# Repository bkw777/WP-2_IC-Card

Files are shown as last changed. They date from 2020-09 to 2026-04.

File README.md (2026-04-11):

# Expansion IC-Card for [TANDY WP-2](tandy.wiki/WP-2), [TANDY WP-3](https://www.retrocoding.uk/tandy-wp-3-word-processor/), [Citizen CBM-10WP](https://web.archive.org/web/20221129054710/http://mo5.com/musee-machines-cbm10wp.html), [NTS WP-10C](https://munk.org/typecast/2020/09/09/tandy-wp-2-user-manual-happy-septandy/)

The TANDY WP-2 and other clones of the Citizen CBM-10WP have an expansion slot that accepts ["IC Cards"](#reference-material).

Here are a few different cards to fit that slot.

* A [battery-backed SRAM card](#sram-card) like the original cards  
* A [non-volatile MRAM card](#mram-card), a RAM card that doesn't need a battery  
* A [ROM card](#rom-card), there is [new software](SOFTWARE) that runs from a rom card but no known images of any old original rom cards  
* A [programming adapter](#programming-adapter) that can read and write both the RAM and ROM cards outside of the WP-2
* A [bus-tap/breakout card](#bus-tap) to allow connecting the bus to a breadboard or logic analyser etc

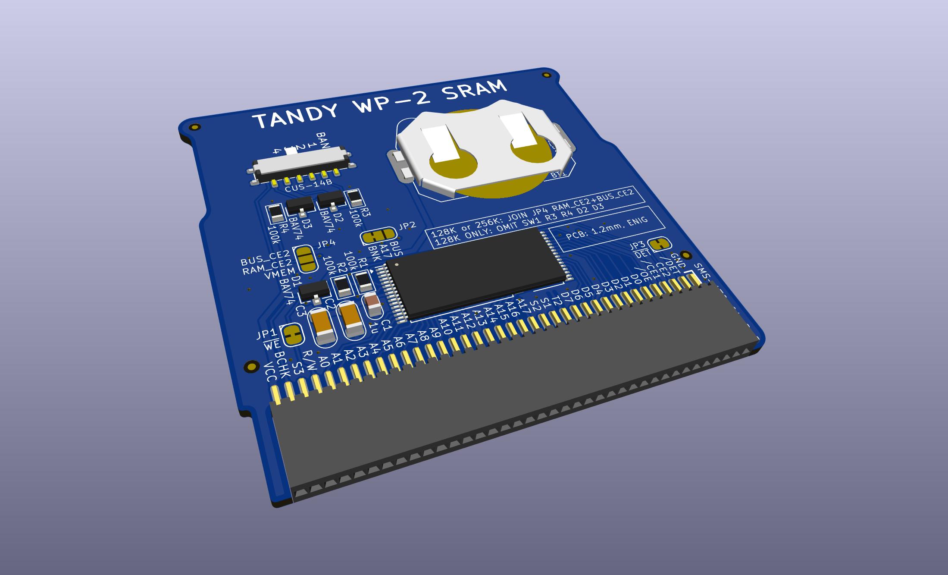
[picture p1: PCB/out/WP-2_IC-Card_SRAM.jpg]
  
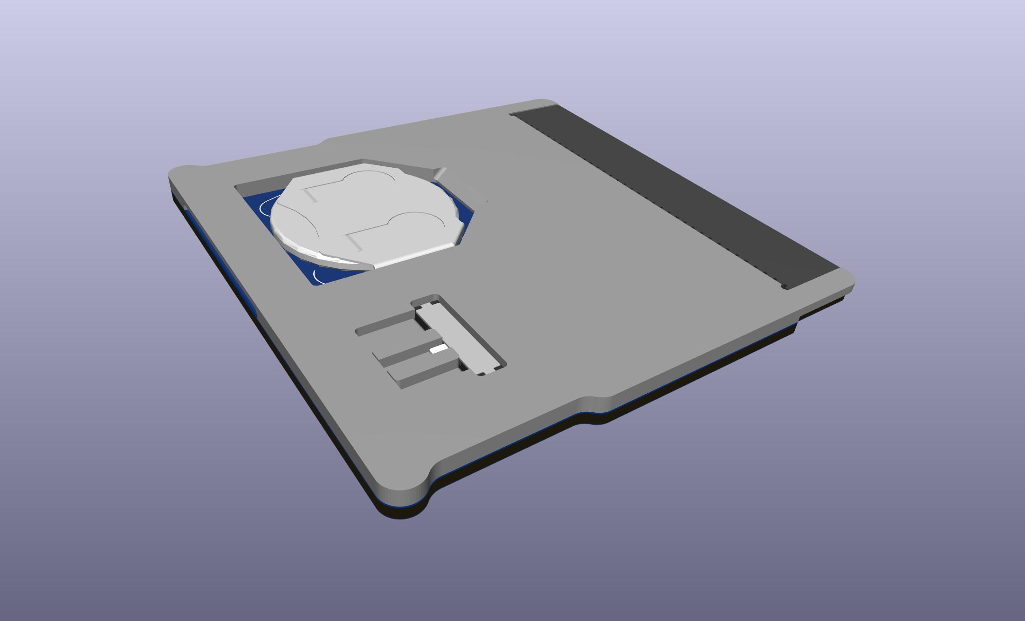
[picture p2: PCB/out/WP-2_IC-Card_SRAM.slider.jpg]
  

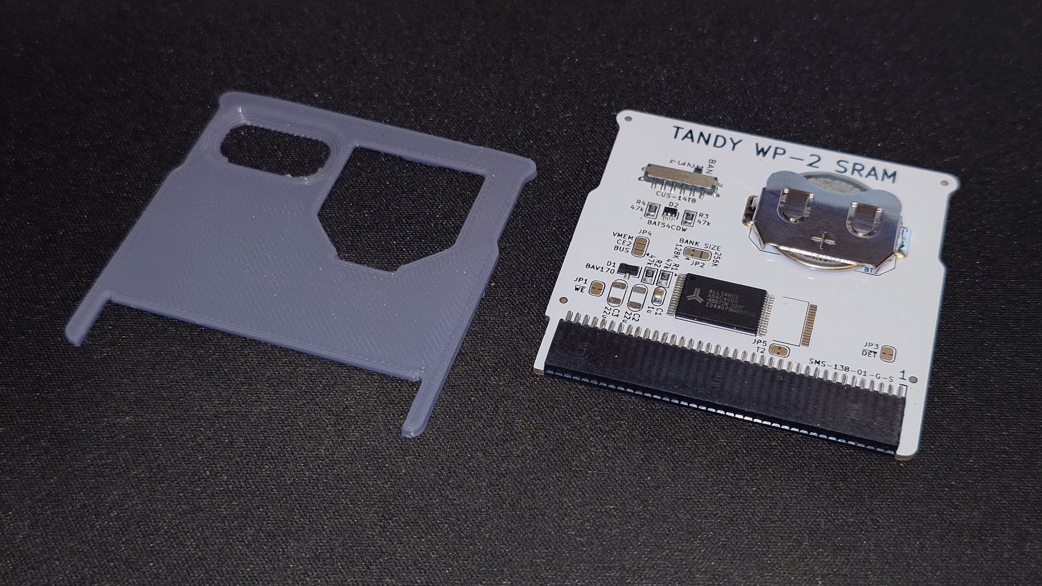
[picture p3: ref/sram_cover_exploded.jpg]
  
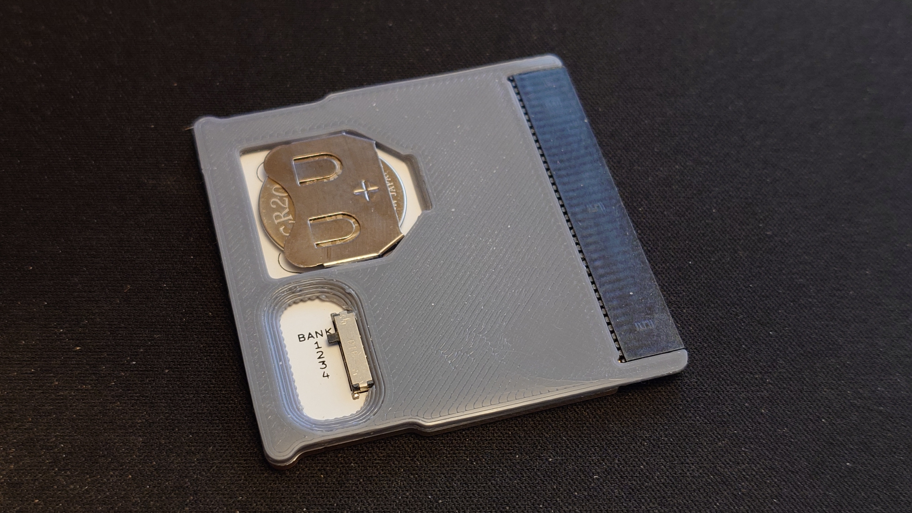
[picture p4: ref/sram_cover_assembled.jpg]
  
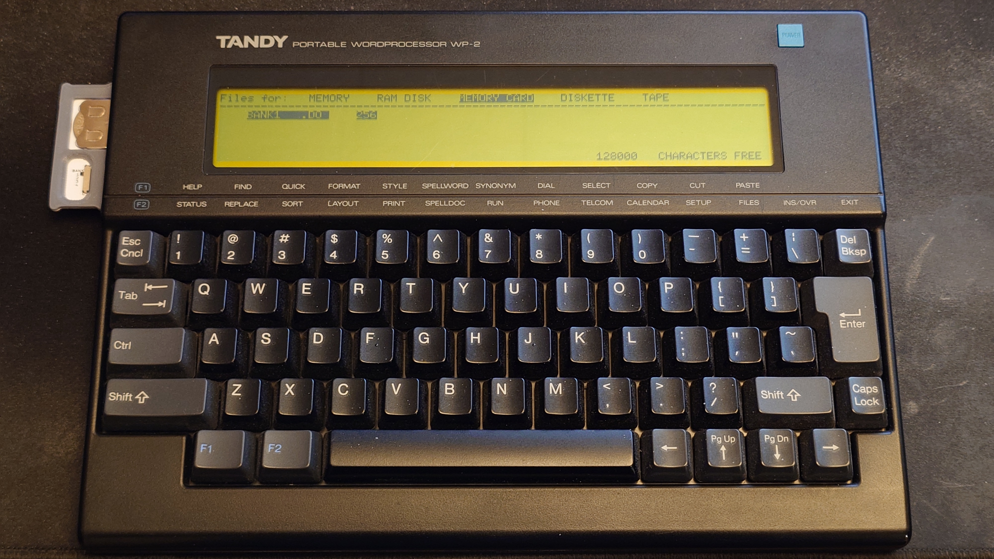
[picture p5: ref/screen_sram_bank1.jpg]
  

## Fabrication & assembly notes

* **REQUIRES 1.2mm PCB**  
The normal default PCB thickness of 1.6mm will NOT fit.  
If you don't remember to manually change the PCB THICKNESS to 1.2mm when ordering, you'll get 1.6mm.  

1.2mm  
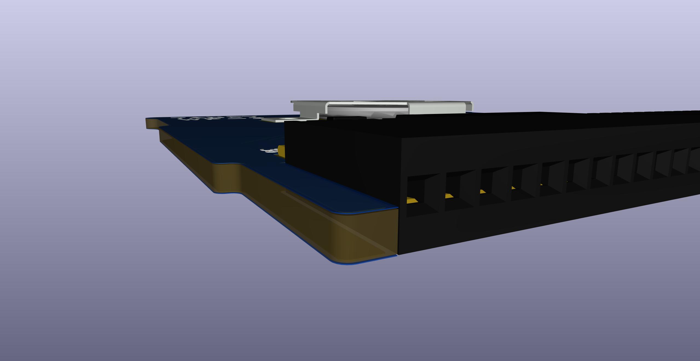
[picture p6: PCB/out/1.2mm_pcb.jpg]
  

1.6mm  
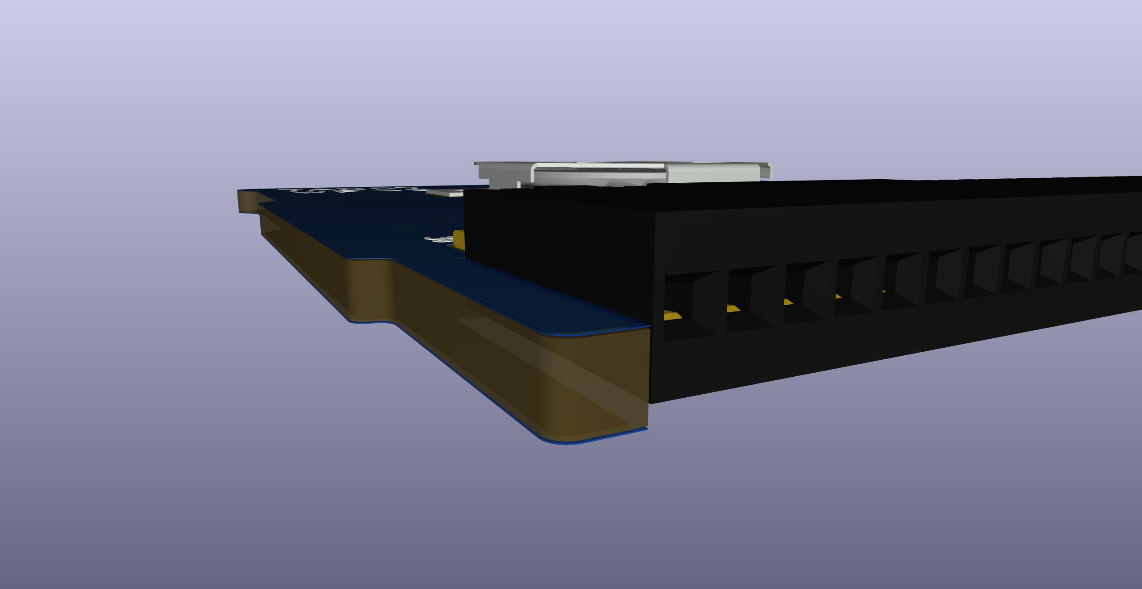
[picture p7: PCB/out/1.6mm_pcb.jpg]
  

* The SRAM card has a battery terminal that should be gold.
ENIG copper finish will give you a better battery terminal without the expense and custom steps of proper selective hard gold.

* Attach the cover with thin 3mm or 1/8" adhesive transfer tape aka "cell phone / tablet screen repair tape".  
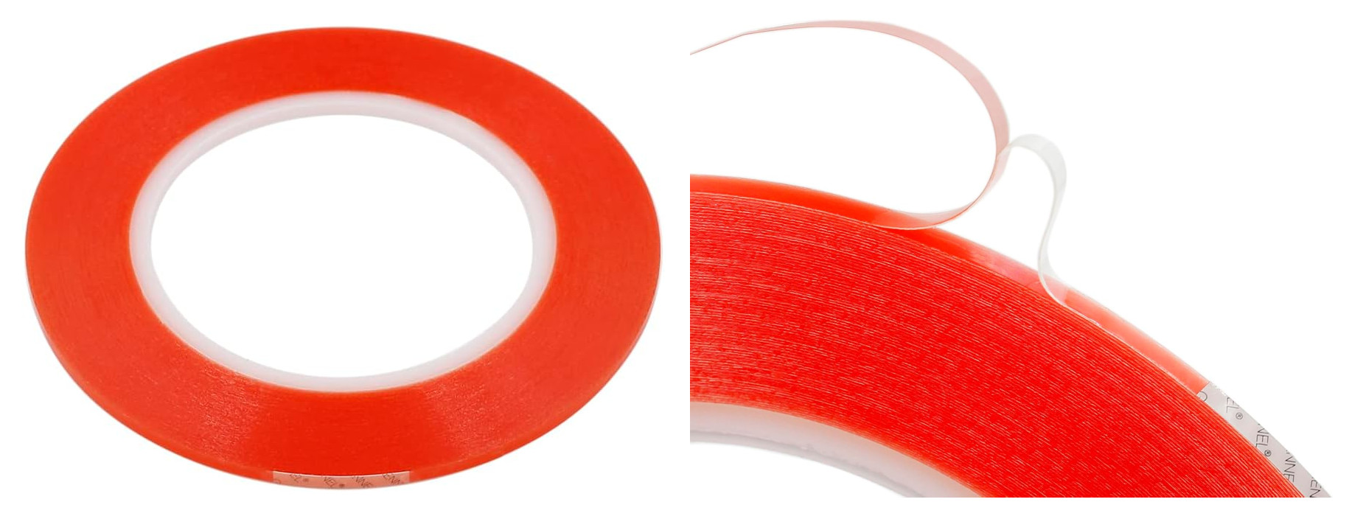
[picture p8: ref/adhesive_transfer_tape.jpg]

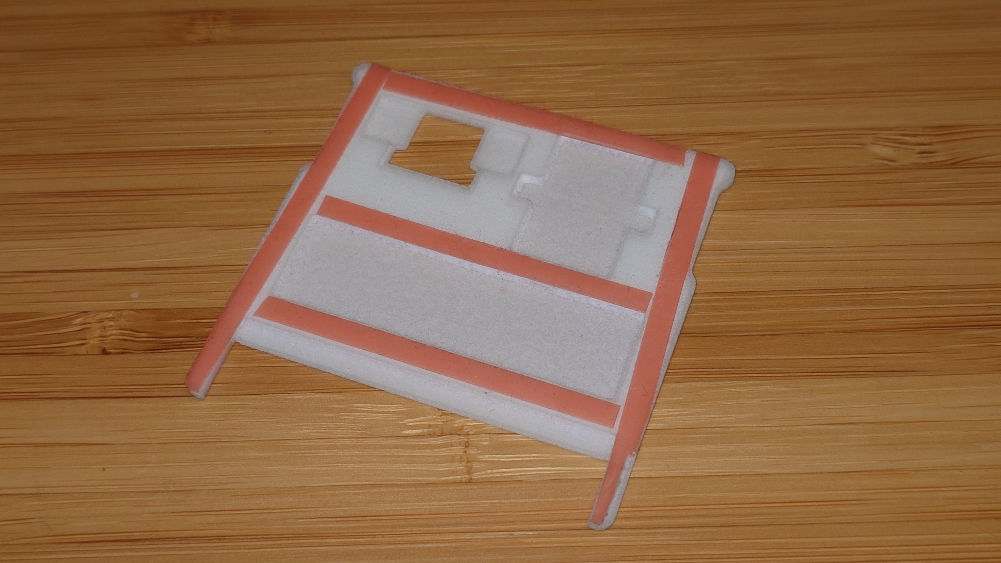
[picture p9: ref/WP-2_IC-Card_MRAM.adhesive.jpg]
 
https://www.amazon.com/dp/B0C78LJLDR/ 0.2mm  
https://www.amazon.com/dp/B0DRV5D4YG/ 0.2mm  
https://www.amazon.com/dp/B078H298G2/ 0.2mm  
https://www.amazon.com/dp/B019OQ4ZG0/ 0.2mm  
https://www.amazon.com/dp/B01N27LYV9/ 0.09mm  

<!-- https://amazon.com/dp/B06Y34587N/ (This one is wider than 5mm but has no carrier film in the middle, just gummy adhesive that squishes into any form, so the width doesn't matter and you can just lay it anywhere right over the chips and pins etc.) -->
Or glue, but adhesive is easier to remove later.  
You can make the cover easy to remove by just using small bits of tape instead of full lengths like the picture. It doesn't take much to hold it on

The cover is not just cosmetic. It prevents the components from catching on the lip of the card slot when inserting & removing, and protects against shorts, and protects against general physical damage to the components.

Similarly, it's a good idea to cover the bottom of the pcb with a piece of 2 inch shipping or packing tape to protect the pcb from scratching and shorting.  
Just lay a simple single piece across the main pcb part along the connector edge but not on the connector.

The various solder-jumpers are mostly for hacking and custom software development like making a ram card emulate a rom card, or possible use in other machines besides the WP-2, for instance maybe some other machine besides the WP-2 could address 256k in ram mode, etc.  
They are pre-connected for normal operation and you normally just ignore them. Don't solder them or cut them.  

The most likely exceptions you might actually use are:  
. On the ROM card, to make a simple 256k rom card with no bank switch or write-enable switch, hard-wired to always be write-enabled via the S3 pin to work with a matching bodge wire mod in the WP-2, solder-blob the S3 pin pads on the (unpopulated) write-enable switch.  
. On the SRAM card, to make a simple 128k ram card with no bank switch, solder-blob RAM_CE2 to BUS_CE2 (or RAM_CE2 to VMEM, it doesn't much matter which, but only one or the other not both!)

Most cards have a few different styles and configurations of the printed cover.  
If you have trouble printing the fancy switch sliders, the "finger" versions are a simpler alternative.  
The switches are optional on all cards, so there are versions without any bank-select or write-enable switches.  
Aside from the pre-generated stl files, you can open the scad file in openscad and use the customizer panel to select different options and generate a new stl file. You don't have to touch the scad code. Just play with a few of the main options at the top of the customizer panel.

Gerbers, BOMs, and STLs are in [releases](../../releases/)

[pictures](https://photos.app.goo.gl/M8KbMLbY8BXGH7LL8)

----

## SRAM CARD  
<!--
[128K SRAM BOM from DigiKey](https://www.digikey.com/short/fdjd3j85)  
[128K SRAM PCB and COVER from PCBWAY](https://www.pcbway.com/project/shareproject/WP_2_RAM_IC_Card.html)  
IMPORTANT, when ordering the PCB:  
* **Thickness: 1.2** <-- MOST IMPORTANT - DO NOT MISS  
* **Min Track/Spacing: 6/6mil**  
The PCBWAY ordering page may auto-select thinner minimum traces which is expensive, but thise pcb actually has all traces at least 0.2mm (7.8mil), so you should manually change the option to 6mil.  
* **Surface Finish: Immersion gold(ENIG)**  
Makes it expensive, but you want the battery terminal to be gold.  
* **Other Special request: Bottom solder mask full cover.**  
There are no openings in the bottom soldermask layer, so you have to tell them that you want 100% soldermask coverage rather than 0% coverage.

You can save some money on the ENIG by using Elecrow instead of PCBWAY.

![](PCB/out/WP-2_IC-Card_SRAM_128K.jpg)  
![](PCB/out/WP-2_IC-Card_SRAM_128K.covered.jpg)  
![](PCB/out/WP-2_IC-Card_SRAM_128K.top.jpg)  
![](PCB/out/WP-2_IC-Card_SRAM_128K.bottom.jpg)  
![](PCB/out/WP-2_IC-Card_SRAM_128K.svg)  
![](COVER/out/WP-2_IC-Card_Cover_SRAM.png)

****
### work in progress updated SRAM card
-->

Fully populated for a 256k or 512k chip  


Configured for a 128k chip  
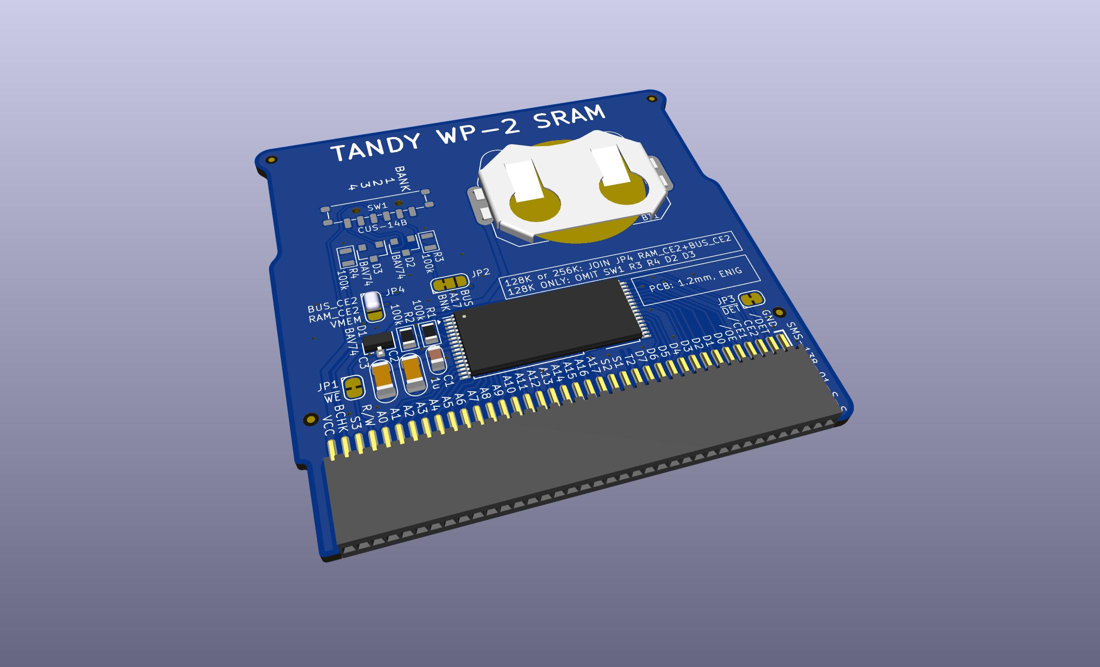
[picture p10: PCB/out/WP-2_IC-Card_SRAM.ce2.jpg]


  
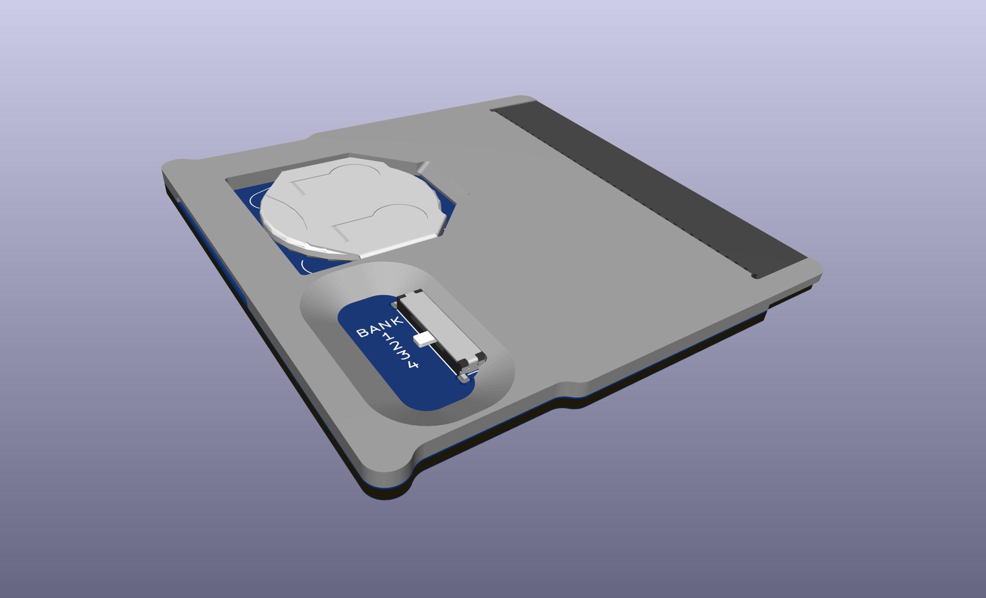
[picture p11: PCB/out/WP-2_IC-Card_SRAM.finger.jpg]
  
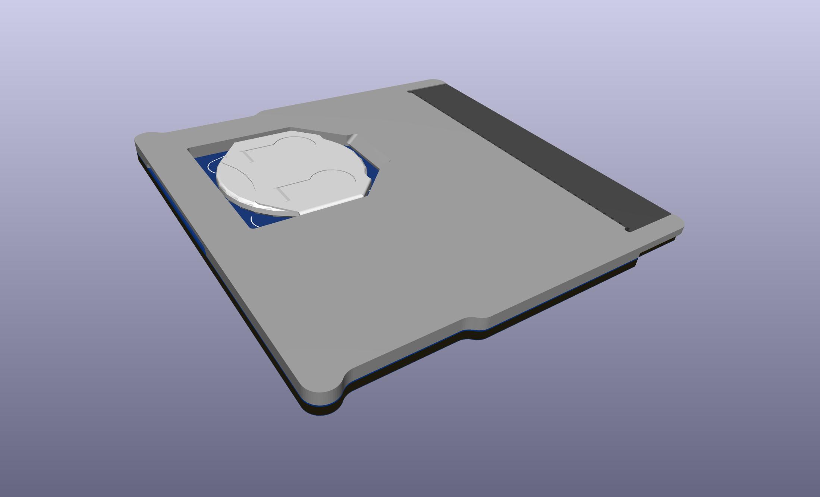
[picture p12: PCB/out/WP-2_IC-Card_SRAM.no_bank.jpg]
  
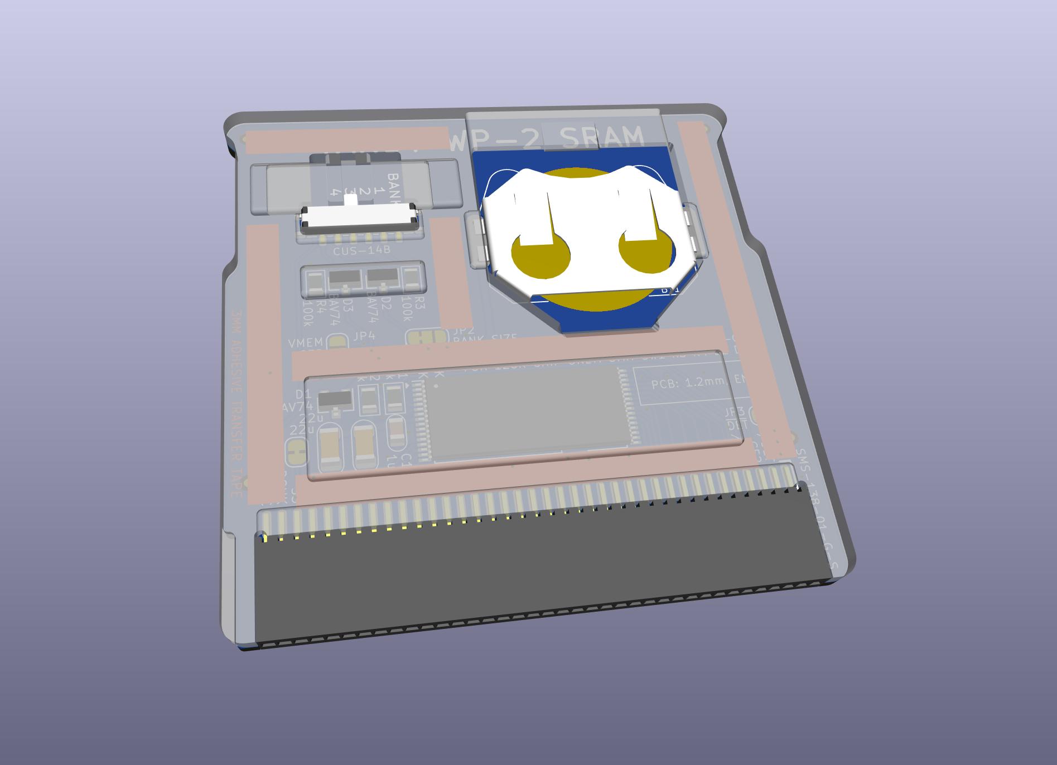
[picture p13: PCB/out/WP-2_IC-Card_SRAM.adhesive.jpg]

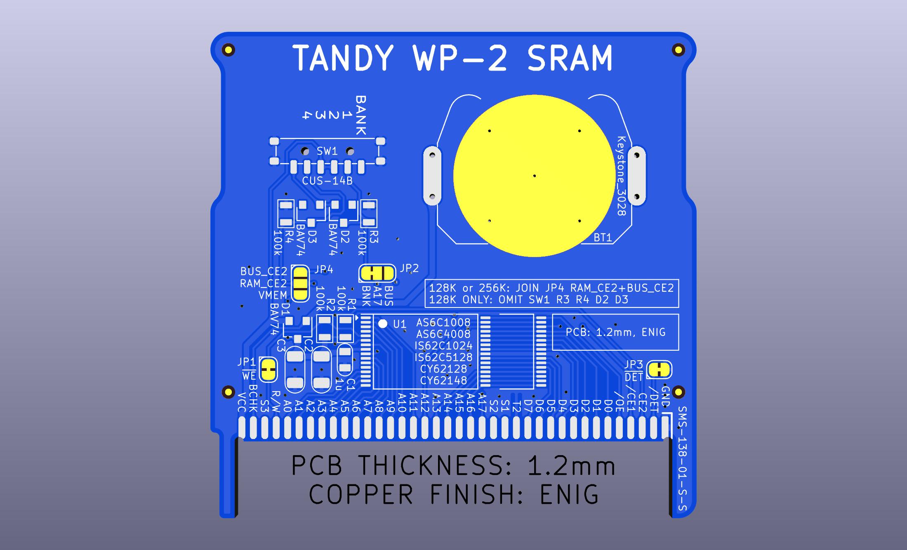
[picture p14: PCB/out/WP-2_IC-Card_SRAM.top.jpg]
  
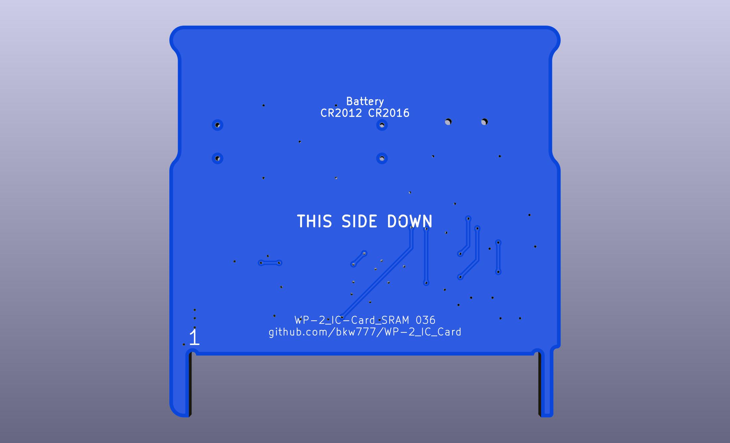
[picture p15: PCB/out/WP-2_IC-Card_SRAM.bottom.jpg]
  


[BOM from DigiKey (512k)](https://www.digikey.com/short/2rpt9c9w)  ([(128k)](https://www.digikey.com/short/qqcwz9tr))  
[PCB and COVER from PCBWAY](https://www.pcbway.com/project/shareproject/WP_2_RAM_IC_Card.html)

<!--
(These links are for an earlier simpler version of the card without any banks. It still accepts any size chip from 128K to 512K, but only uses 128K.)  
[128K SRAM PCB and COVER from PCBWAY](https://www.pcbway.com/project/shareproject/WP_2_RAM_IC_Card.html)  
[128K SRAM BOM from DigiKey](https://www.digikey.com/short/fdjd3j85)  
-->

<!--
WP-2_IC-Card_Cover_SRAM_slider.stl is a cover with a sliding actuator for the bank switch  
WP-2_IC-Card_Cover_SRAM_finger.stl is a cover with a simple concave opening for the bank switch  
WP-2_IC-Card_Cover_SRAM_none.stl is a cover with no bank-switch opening  
-->

<!-- [128K SRAM PCB and COVER from PCBWAY](https://www.pcbway.com/project/shareproject/WP_2_RAM_IC_Card.html)  -->

<!-- When ordering the PCB:  -->
<!-- * **Thickness: 1.2** DO NOT FORGET  -->
<!--
* **Min Track/Spacing: 6/6mil**  
The PCBWAY ordering page may auto-select thinner minimum traces which is expensive, but thise pcb actually has all traces at least 0.2mm (7.8mil), so you should manually change the option to 6mil.  
-->
<!-- 
* **Surface Finish: Immersion gold(ENIG)**  (for the battery)  
* **Other Special request: "Bottom solder mask full cover."**  
-->
<!-- There are no openings in the bottom soldermask layer, so you have to tell them that you want full soldermask instead of none.  -->

<!-- Elecrow produces ENIG cheaper than PCBWAY. Just upload the gerber zip from [releases](../../releases) -->
<!--
For 128K (AS6C1008, IS62C1024, etc):  
  Don't populate SW1, D1, R3, R4  
  Solder-bridge JP4 VMEM-CE2  
  Print the "SRAM_none" cover  
-->

----

## MRAM Card

RAM card without a battery!

This card is expensive.  
The BOM cost is over $50 before tax or shipping and not including the PCB or the 3d-printed top cover.  
The total including PCB, BOM, printed cover, tax, & shipping is over $100.

However it does provide **4** 128k cards in a single card, without any battery.

Supports both a 512K chip with a bank-select switch for 4 x 128K banks, or a 128K chip and you simply omit the indicated bank-select parts.

NOTE: MRAM is permanently damaged by strong magnetic fields.  
The BOM here specifies the Industrial grade version of the chip which claims to be able to tolerate up to 125 gauss.  
The Commercial and Automotive versions are only safe to 25 gauss. A fridge magnet is 100-300 gauss.  
Even with the Industrial part you should still avoid exposure to magnetic fields.  

You may want to store the card in a [steel candy tin](https://www.amazon.com/dp/B0DRBBZR8V),  
with 5-10mm thick shipping foam affixed to the inside top & bottom surfaces, so that the card is suspended away from the top or bottom surface.  
The 4 edge walls aren't a problem because the center of the mram chip isn't near a card edge.  
Magnetic fields drop off rapidly with distance, so suspending the card even just 6mm away from the inside walls makes even more difference than the steel shell.  

This protects against many common magnetic sources that measure in the 100-1000 gauss range.  
Some examples: large over ear headphones, bluetooth speaker, cell phone, laptop lid, "refrigerator" magnets, tablet cover, handbag closer, magnetic usb-c cable end.  
But for example a 3900 gauss (very strong) flashlight handle stuck to the outside of the can still measures 500 gauss at the surface of the foam, which is still too high.  
For long-term storage, you may want to just keep it in a larger box & filler that simply adds at least another inch (20-30mm) of distance on all sides.

[512K MRAM PCB and COVER from PCBWAY](https://www.pcbway.com/project/shareproject/512k_MRAM_IC_Card_for_TANDY_WP_2_30f542a7.html)  
[512K MRAM BOM from DigiKey](https://www.digikey.com/short/d22n7358)

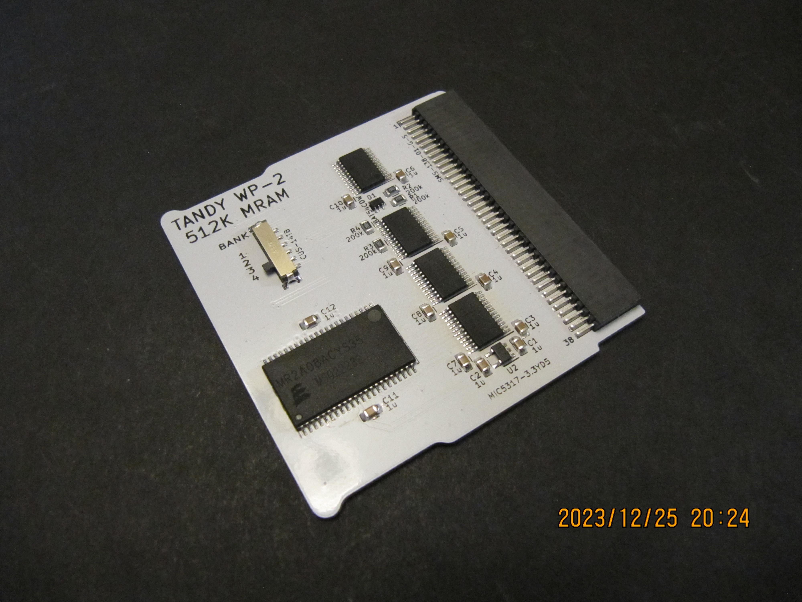
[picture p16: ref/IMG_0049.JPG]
  
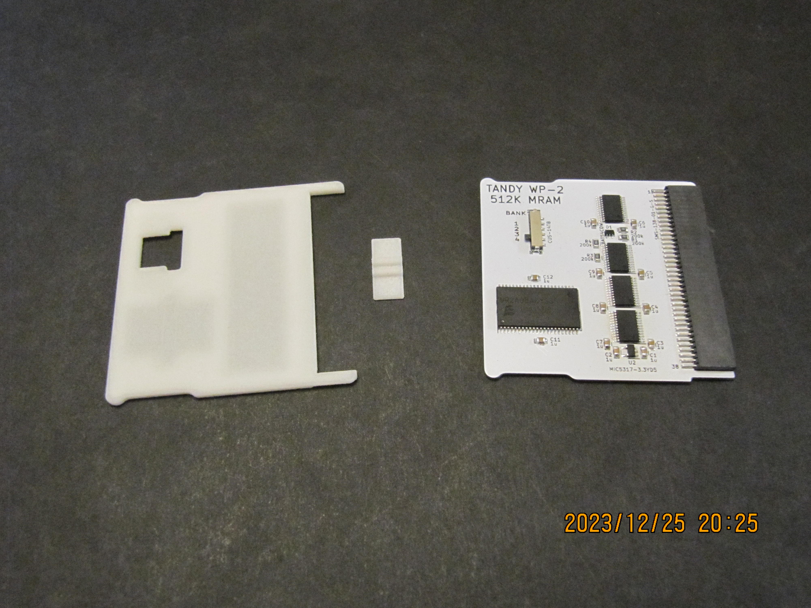
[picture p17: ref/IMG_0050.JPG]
  
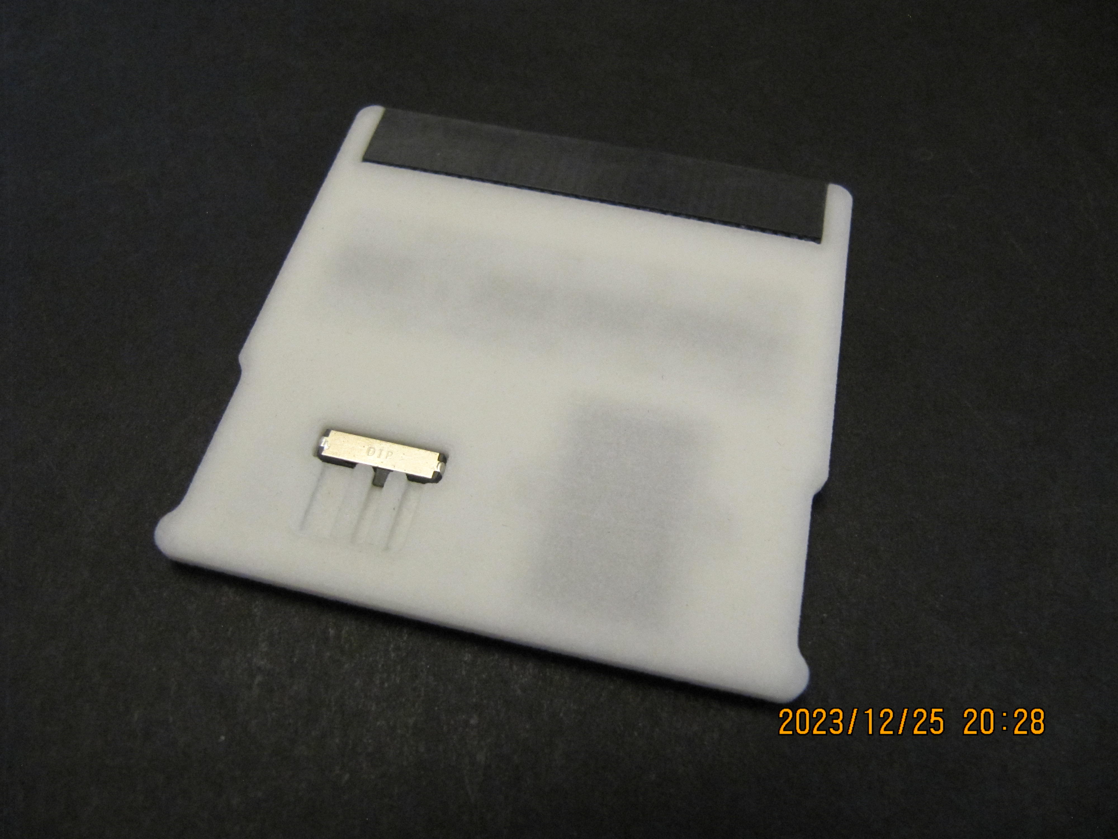
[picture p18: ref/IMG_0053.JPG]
  
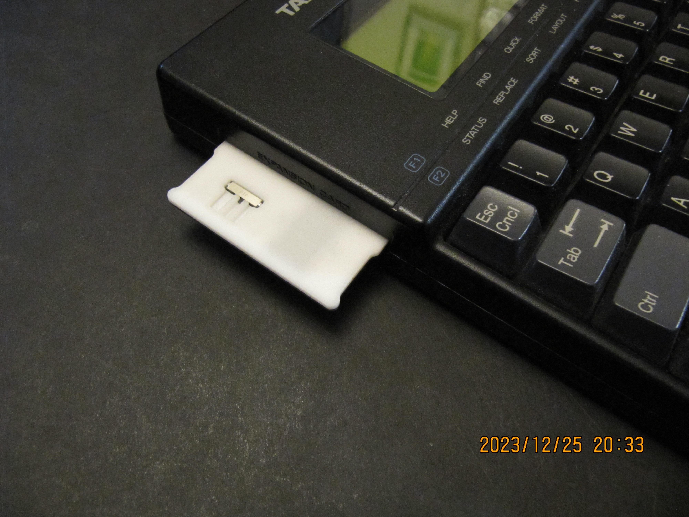
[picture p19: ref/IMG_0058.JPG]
  
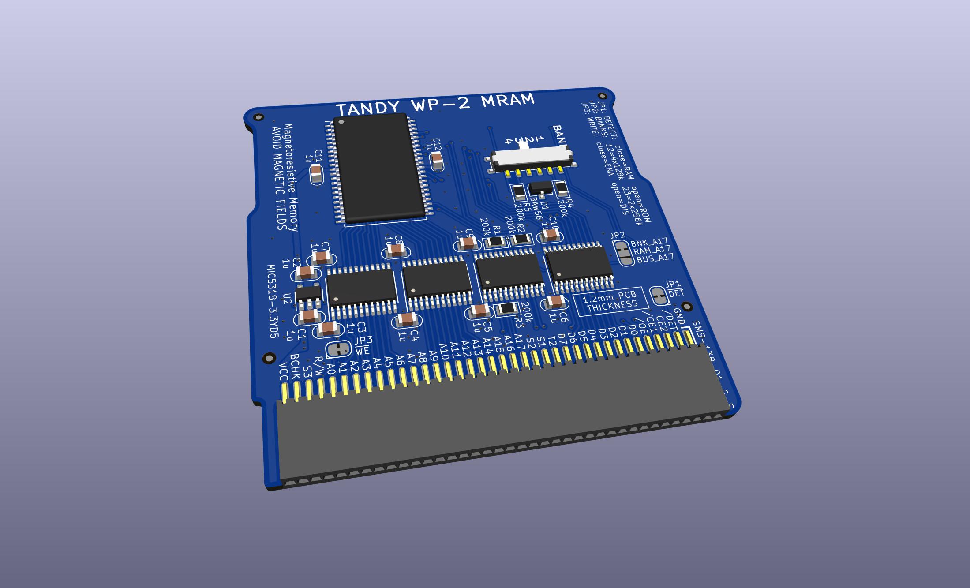
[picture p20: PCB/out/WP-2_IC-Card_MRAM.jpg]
  
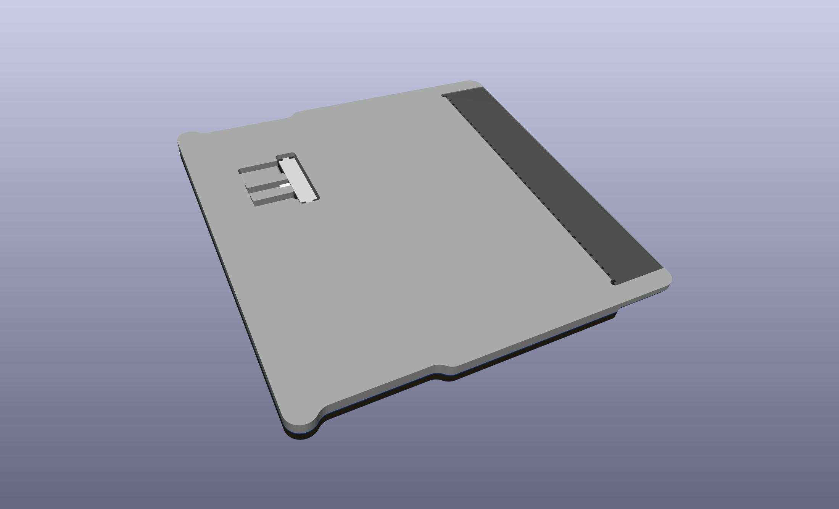
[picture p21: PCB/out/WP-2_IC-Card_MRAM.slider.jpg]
  
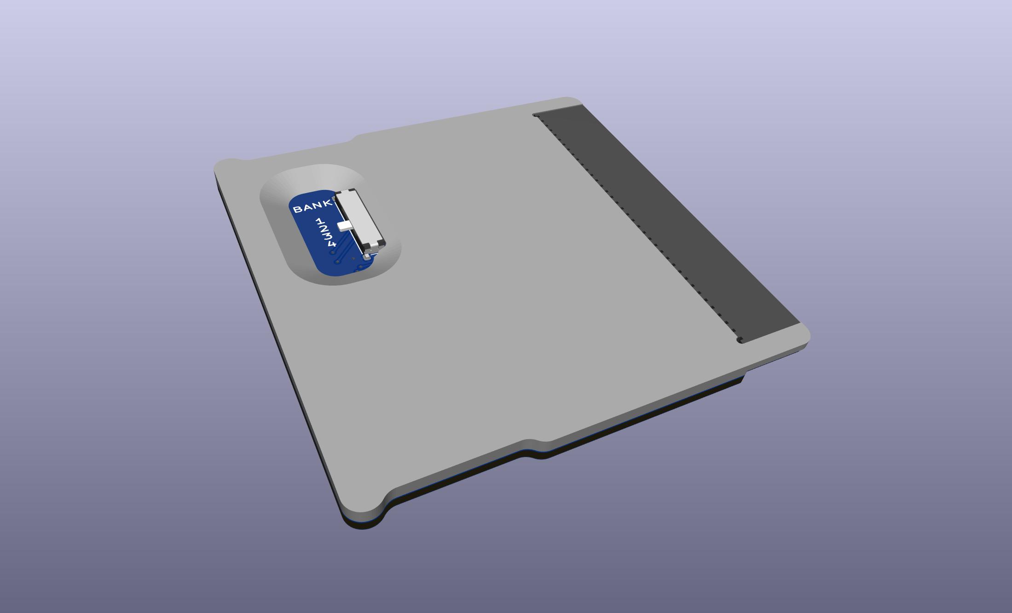
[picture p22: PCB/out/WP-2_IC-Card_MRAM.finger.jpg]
  
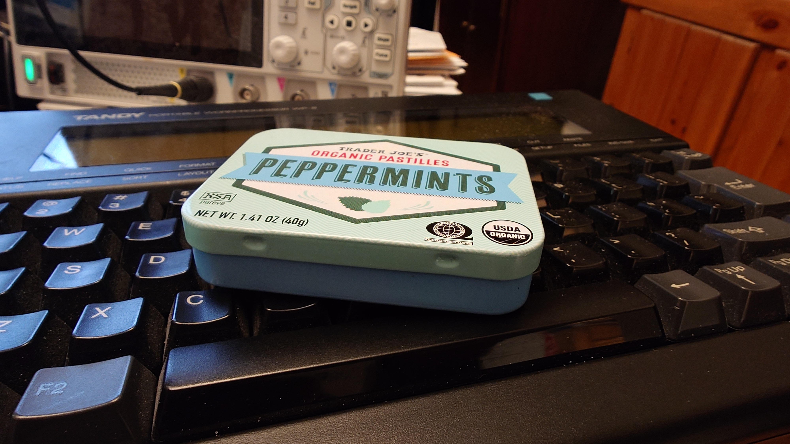
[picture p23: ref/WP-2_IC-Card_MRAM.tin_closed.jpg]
  
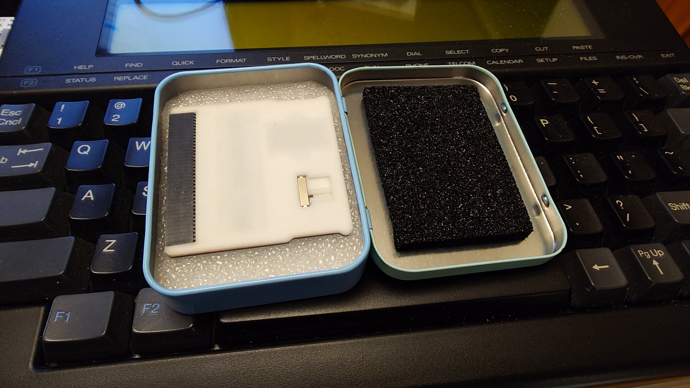
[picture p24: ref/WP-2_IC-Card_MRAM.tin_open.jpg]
  
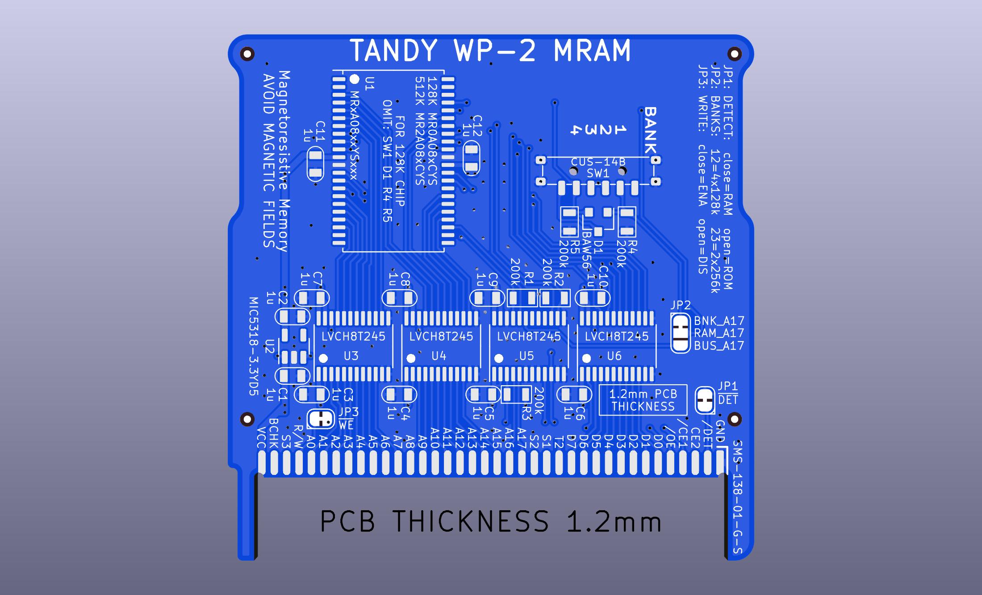
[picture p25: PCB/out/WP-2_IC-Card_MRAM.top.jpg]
  
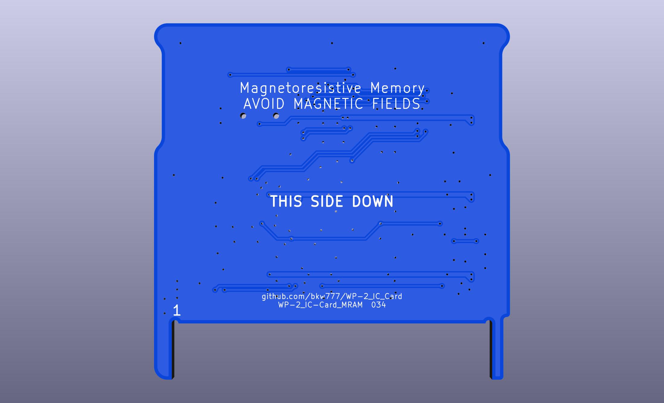
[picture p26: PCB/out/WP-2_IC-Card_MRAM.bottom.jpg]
  


----

## ROM CARD  

<!-- [ROM card PCB from OSHPark](https://oshpark.com/shared_projects/F9gte3be) (Select 0.8mm PCB thickness)  -->
[ROM PCB and COVER from PCBWAY](https://www.pcbway.com/project/shareproject/WP_2_ROM_IC_Card.html)  
[ROM BOM from DigiKey](https://www.digikey.com/short/3f4nmrp4) (256K & no bank sw)

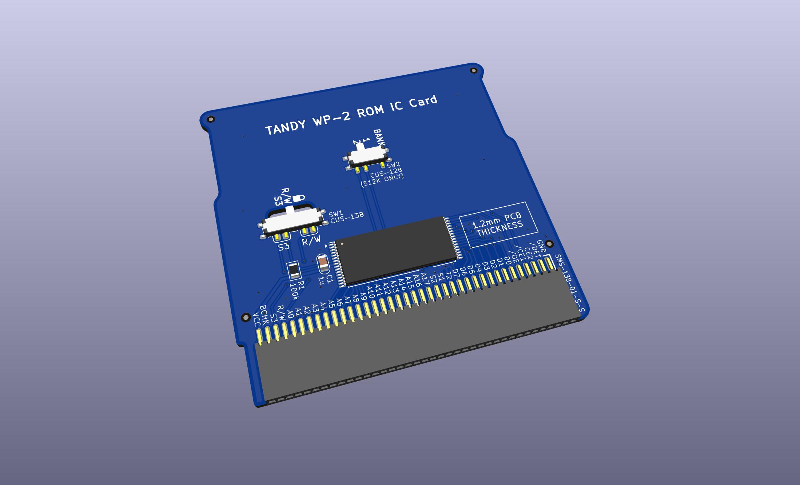
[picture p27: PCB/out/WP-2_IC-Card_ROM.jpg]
  
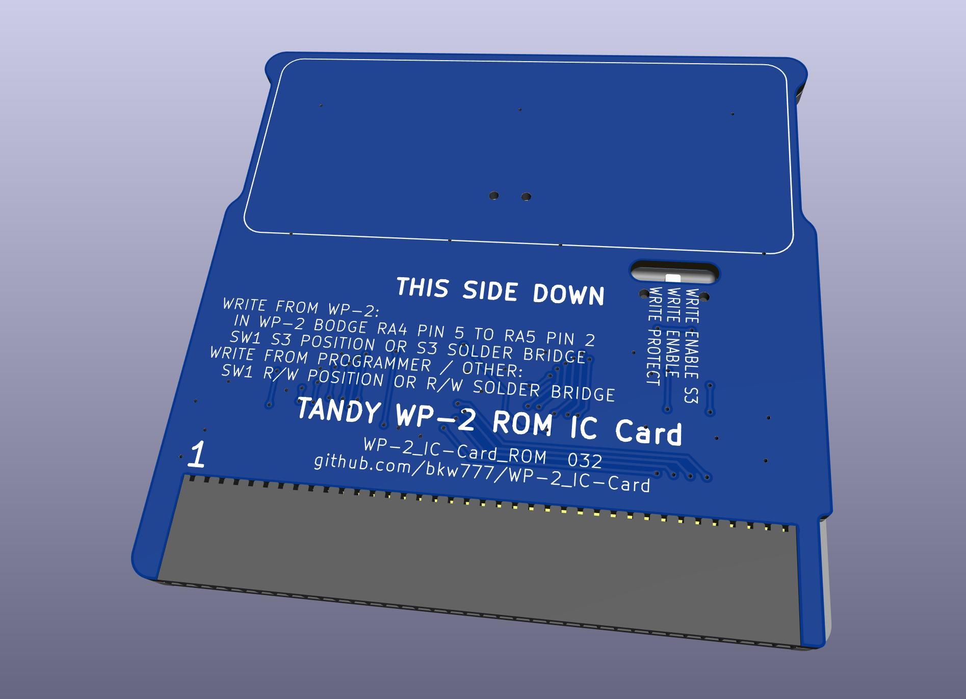
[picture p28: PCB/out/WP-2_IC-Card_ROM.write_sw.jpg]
  
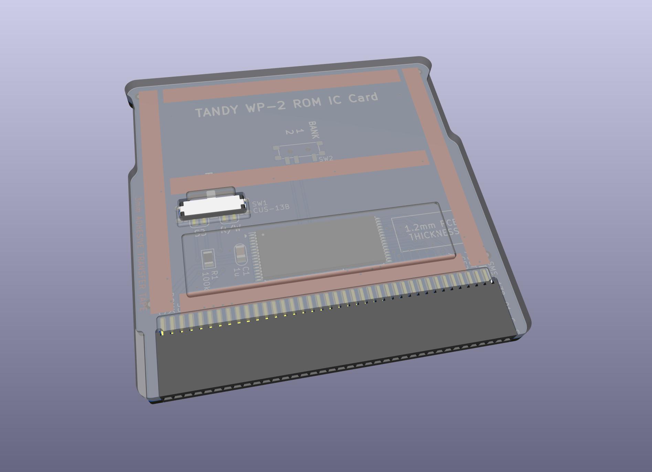
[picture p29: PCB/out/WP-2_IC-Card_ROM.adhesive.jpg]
  

SW1 is optional. The marked S3 and R/W pads double as solder jumpers.
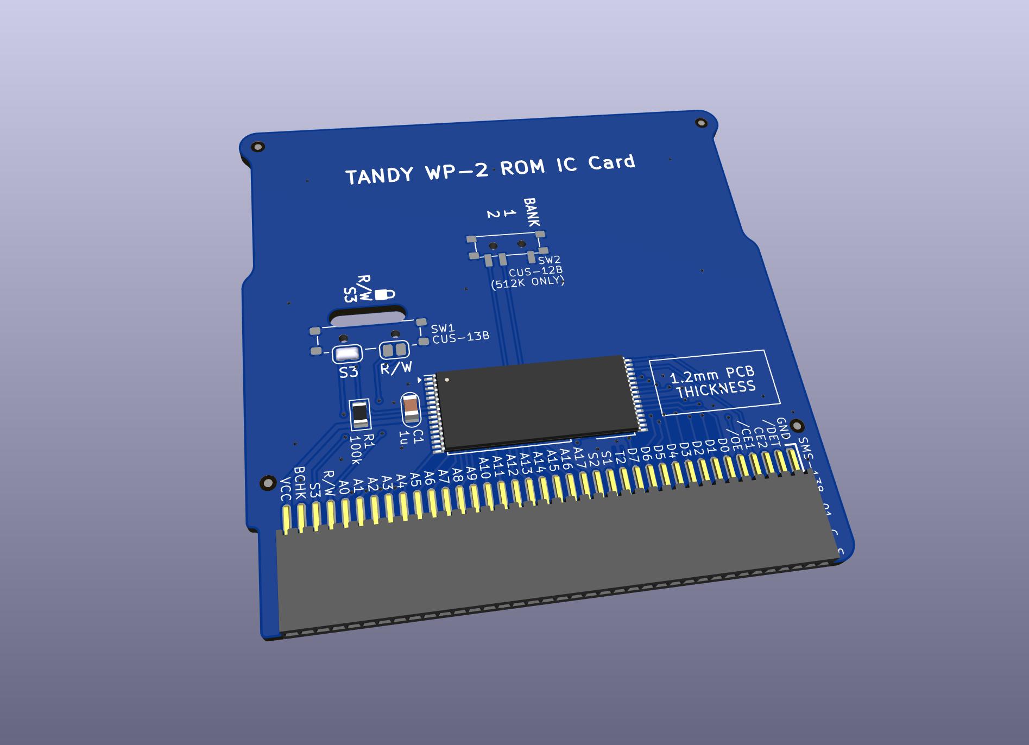
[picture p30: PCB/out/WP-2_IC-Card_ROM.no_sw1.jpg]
  

Fully populated with 512k chip, bank switch, and convenience write-enable switch.  
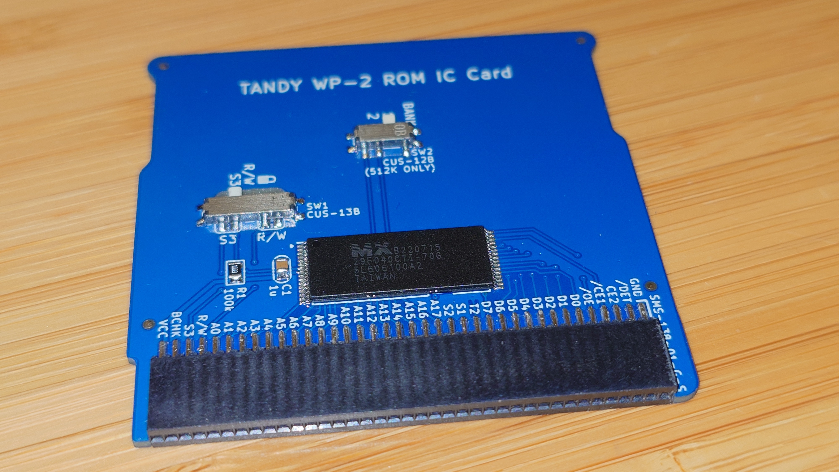
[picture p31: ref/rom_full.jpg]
  

Minimal config with 256k chip, no bank switch, solder blob for WP-2 S3 pin write mod.  
R1 is not ideal or wanted here because it is a pullup on /WE, and in this configuration, the /WE line is connected to both the S3 and /WR pins inside the WP-2, and they both already have 100k pullups each.  
If you leave the solder blob on, then you don't need R1. If you remove the solder blob, then you need R1. Same for the R/W position or S3.  
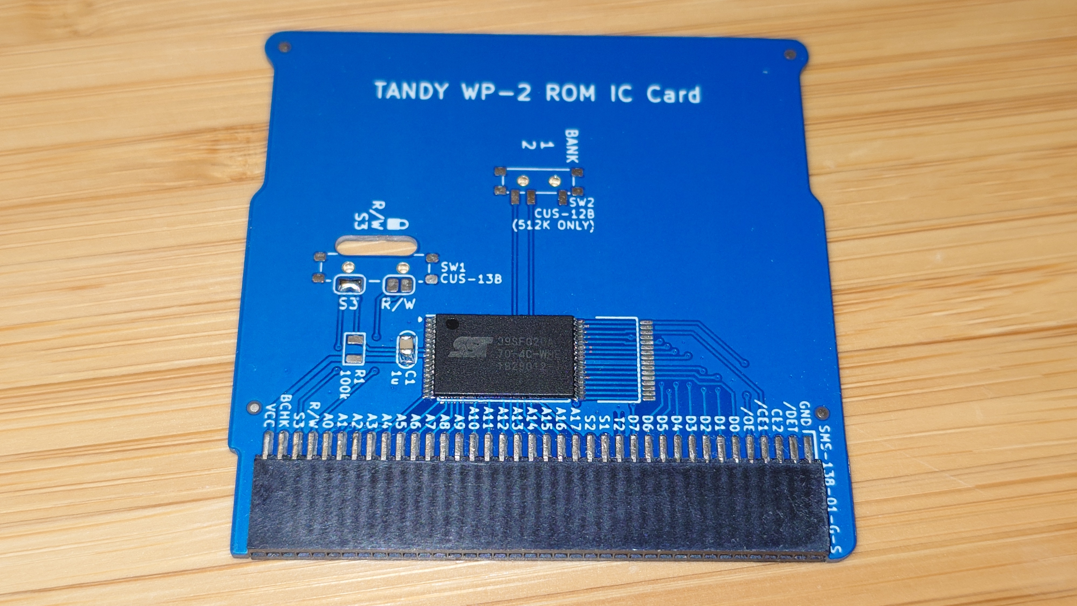
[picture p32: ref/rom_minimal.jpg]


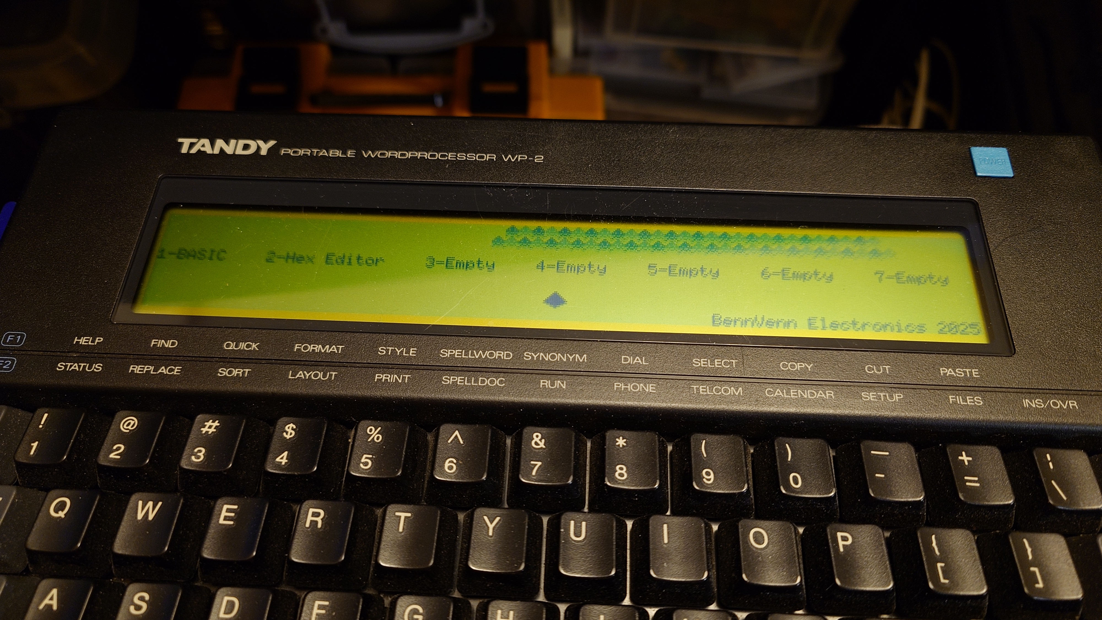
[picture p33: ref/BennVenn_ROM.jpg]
  
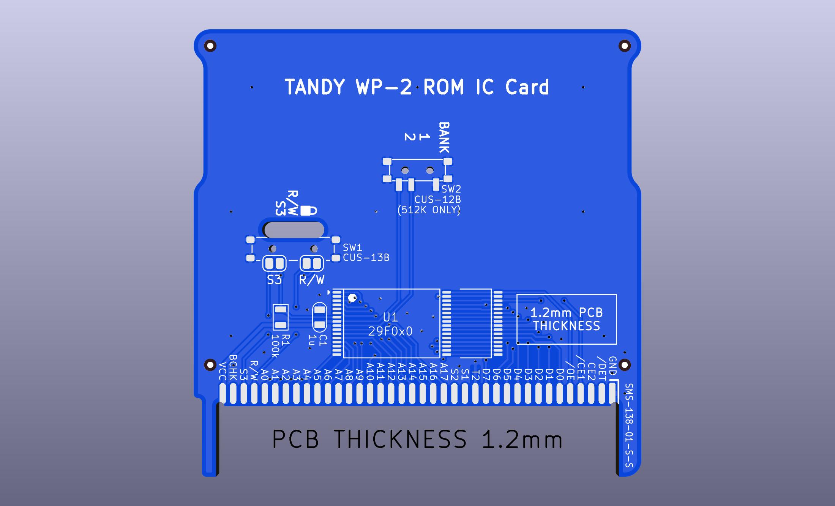
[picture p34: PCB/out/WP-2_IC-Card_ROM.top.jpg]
  
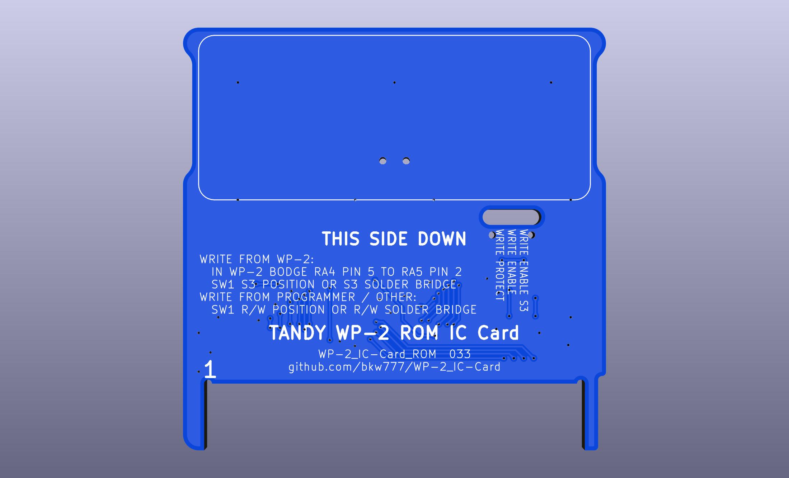
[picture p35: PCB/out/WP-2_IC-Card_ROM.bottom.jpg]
  


There are 2 options for writing to the ROM card, using a programmer or using software on a modded WP-2.

### Write to the ROM card using a WP-2 with "S3 write mod"

* On the WP-2 mainboard, add a bodge wire connecting RA4 pin 5 to RA5 pin 2.  
  ( RA4p5 is /WR on the cpu, RA4p2 is pin 36 (S3) on the IC Card connector )  
  This wire can be left there permanently, it doesn't interfere with normal operation.

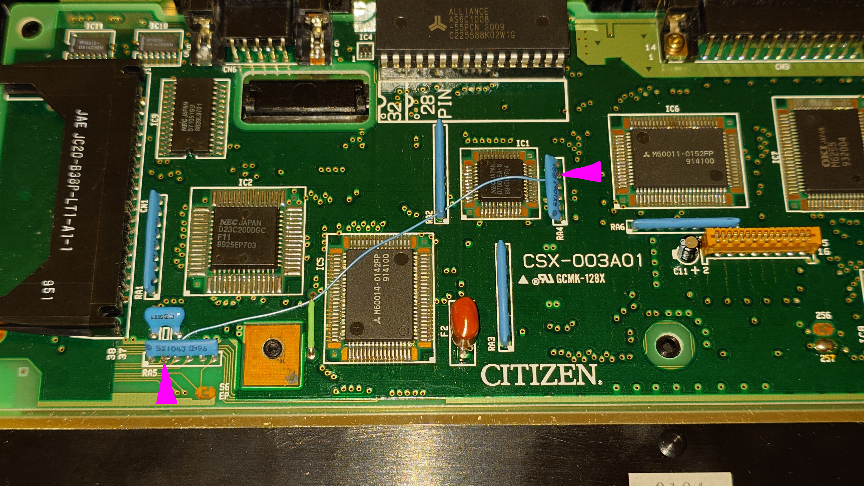
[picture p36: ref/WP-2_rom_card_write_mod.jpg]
    
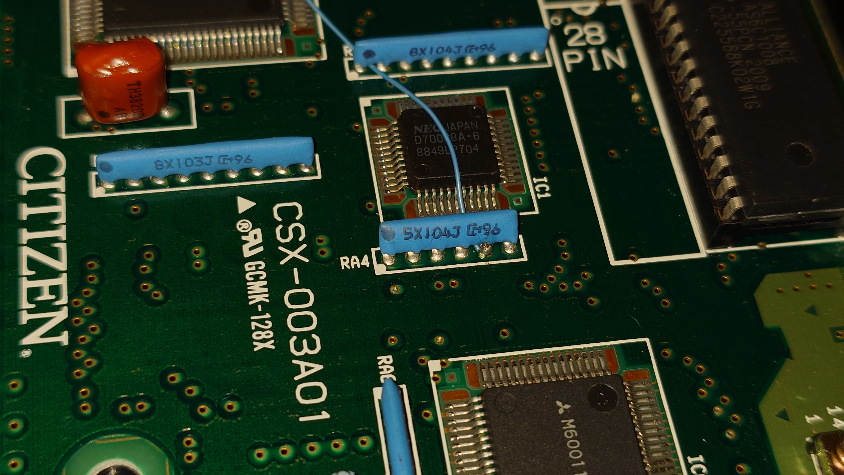
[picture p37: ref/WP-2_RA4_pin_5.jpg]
    
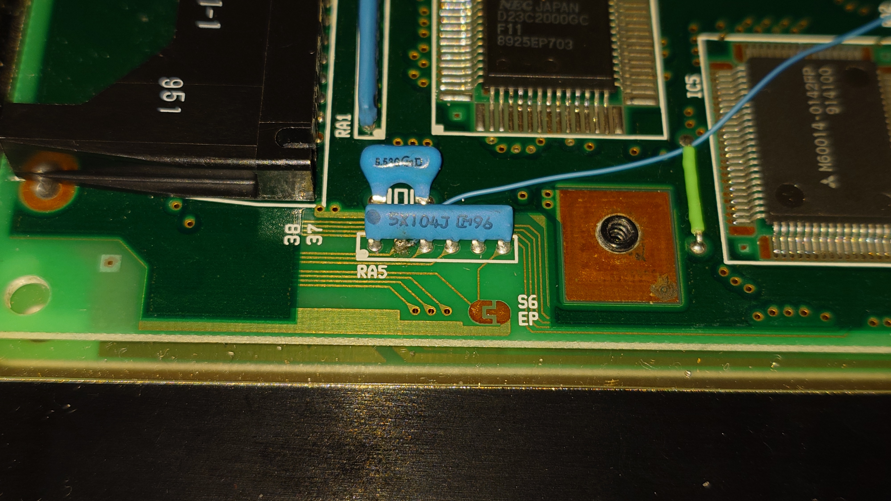
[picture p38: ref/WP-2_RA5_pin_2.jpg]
  

  Solderless option:  
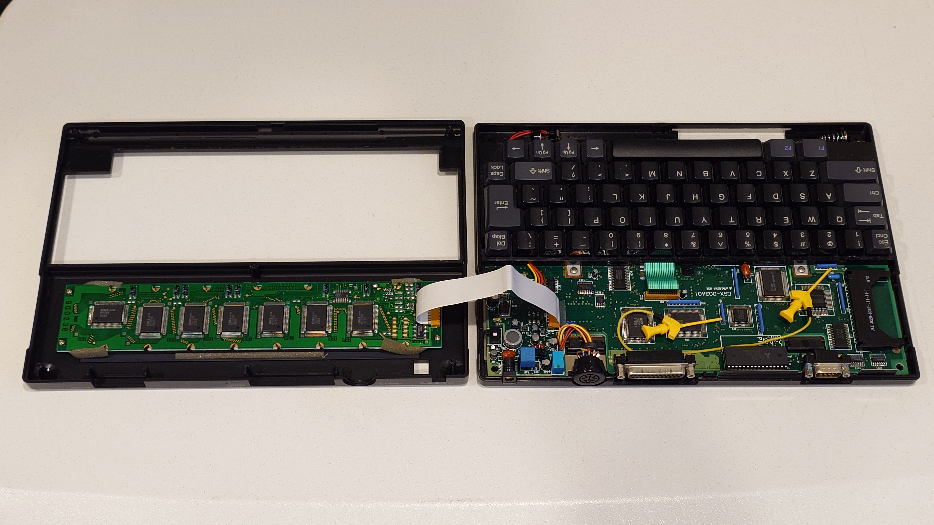
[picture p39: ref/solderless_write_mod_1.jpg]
    
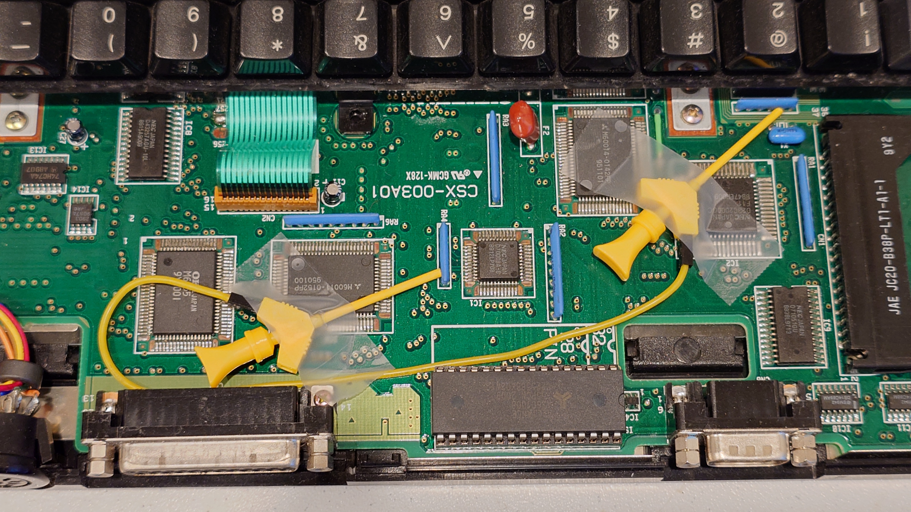
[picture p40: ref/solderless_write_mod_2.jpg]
  

  Notes if using mini-grabbers instead of soldering:  
  * Requires mini-grabbers with a thin body and strong hooks: https://www.amazon.com/dp/B0DL5ZLK8H  
  * Lean X1 away from RA5 slightly to let the grabber reach.  
  * Ensure the RA5 grabber handle lies on the pcb to the side of the square chip, not on top of the chip.  
  * Ensure the RA4 grabber lies angled towards the printer port so that the lcd ribbon doesn't lay on top of the grabber handle when you close the case. The sharp corners on the grabber handle will poke into the cable.  
  The tape in the pic is just to keep the grabbers in the best position long enough to close the case.  
  * Shift & wiggle the case halves back & forth a little while while closing so that the grabber handles get pushed to the sides of the chips where there is just enough room for them so they don't put pressure on the lcd.

* On the card, Select SW1 position S3 or solder-jumper S3 if no switch installed.

* See [SOFTWARE](SOFTWARE) for the software & directions.

### Write to the ROM card using an eprom programmer

* Build the [programming adapter](#programming-adapter) below.

* See [To program the ROM card](#to-program-the-rom-card).

----

## Programming Adapter
The programming adapter supports both ROM and RAM cards.  
Use with a standard eprom programmer such as TL-866 or T48, etc.  

<!-- Minimalist programming adapter. Requires extreme care not to bend the pins when pulling the card off the adapter.  
![](PCB/out/WP-2_IC-Card_programming_adapter.jpg)  
<!-- [Programming Adapter PCB from OSHPark](https://oshpark.com/shared_projects/TkzNwgho)  -->
[Programming Adapter PCB from PCBWAY](https://www.pcbway.com/project/shareproject/TANDY_WP_2_IC_Card_Programming_Adapter.html)  
[Programming adapter BOM from DigiKey](https://www.digikey.com/short/5hhj5749)

  
  


<!-- 
Example reading ROM card, jumpers in ROM position.
![](ref/WP-2_IC-Card_programming_adapter.ROM.jpg)  

Example reading RAM card (SRAM or MRAM), jumpers in RAM position.
![](ref/WP-2_IC-Card_programming_adapter.RAM.jpg)  
-->



### To program the ROM card

Set all 4 jumpers on the programming adapter to ROM.

Set the write-enable switch on the card to the R/W position.

Example using a TL-866 programmer to write a file named `rom.bin` to the ROM card:  
`minipro --device SST39SF020A --unprotect --protect --write rom.bin`

<!-- old version of the breakout card also had a footprint for the rom chip and some extra pins to enable/disable it -->
<!-- current breakout card no longer has that, this is just for reference for TechTangents who has one.-->
<!-- 
### To program the Breakout/ROM card

Same as for ROM card except:

Install a jumper from /CE1 to /CE_IC on the card.  
Install a jumper from R/W to /WE_IC on the card.  (This one takes the place of the male jumper on the normal rom card above)  
Remove jumper from  GND to /DET on the card.  
-->

### Reading/Writing the RAM card

Set all 4 jumpers on the programming adapter to RAM.  
(This makes the pinout of the DIP pins match a standard SRAM chip.)

Examples using a TL-866 programmer:  
This tells the programmer to assume the chip is a "DS1245AB(RW)", which is just a device that the programmer software happens to support, which also happens to function the same way as the card. It's a 5 volt, parallel, 128Kx8 SRAM, with a battery, which is all the same as the card when it's in the programming adapter and the jumpers are all set to RAM.  
`minipro --device "DS1245AB(RW)" --read ram.bin`  
`minipro --device "DS1245AB(RW)" --write ram.bin`

----

<!-- the bus tap card is the new breakout card -->
<!-- 
## BREAKOUT CARD

<!-- [Breakout PCB from OSHPark](https://oshpark.com/shared_projects/4spvX9oV) (Select 0.8mm PCB thickness)  -->
<!--
[Breakout PCB from PCBWAY](https://www.pcbway.com/project/shareproject/TANDY_WP_2_IC_Card_Breakout.html) (Select 1.2mm PCB thickness)  

[Breakout BOM from DigiKey](https://www.digikey.com/short/323npm39)  

![](PCB/out/WP-2_IC-Card_Breakout.jpg)  
![](PCB/out/WP-2_IC-Card_Breakout.svg)
-->

----

## BUS TAP

Breakout card with a card socket to monitor bus signals while a card is in use.  
The VHOST-VCARD pins allow to measure the current drawn by the card.  
VHOST is VCC from the WP-2, VCARD is VCC to the card.  

<!-- [Breakout PCB from OSHPark](https://oshpark.com/shared_projects/4spvX9oV) (Select 0.8mm PCB thickness)  -->
<!-- [Breakout PCB from PCBWAY](https://www.pcbway.com/project/shareproject/TANDY_WP_2_IC_Card_Breakout.html) (Select 1.2mm PCB thickness)  -->

<!-- [Breakout BOM from DigiKey](https://www.digikey.com/short/323npm39)  -->

  
  
  


<!-- ![](PCB/out/WP-2_IC-Card_Breakout.svg) -->

# Moving files between a card and a PC

Connect the WP-2 to a PC via [9 pin female-female rs-232 null-modem cable](https://amazon.com/dp/B00QM8ZP5E) and [usb-serial adapter](https://amazon.com/dp/B074VN9ZG4)(usb-c example), 
or a one-piece [usb-null-modem cable](https://amazon.com/dp/B07DRHB264).

Run [DL2](https://github.com/bkw777/dl2) or [LaddieAlpha](https://bitchin100.com/wiki/index.php?title=LaddieCon#LaddieAlpha) on the pc.

Then use the WP-2 (press `F2`+`=`) to copy files between `MEMORY CARD` and `DISKETTE`.

# Reference Material
[WP-2 Owner & Service Manuals](https://archive.org/search.php?query=Tandy%20WP-2)  
Card slot signals & usage: Service Manual 8-2, C-3.  
Executable "RUN" files: Service Manual 4-16, D-1.

### Connector:  
[Original Connectors](ref/JC20-B38S-F1.pdf)  
Datasheet for both the slot in the computer and the connector in the card.  

You can't get the real connector any more, but you can get a generic socket header which fits the pins.  
The pins inside the card slot are 1 row x 38 pins, 1.27mm pitch, 6.0mm long

SAMTEC 8.5mm Pin Socket  
<https://duckduckgo.com/?q=SMS-138-01>  
<https://www.digikey.com/en/products/detail/samtec-inc/SMS-138-01-G-S/9773732>  
<https://www.mouser.com/ProductDetail/Samtec/SMS-138-01-G-S>

There are much less expensive generic female 1.27mm pin headers on ebay and aliexpress, but they don't work for this. Sorry :/ The metal parts inside the cheap connectors aren't held in place accurately enough, and the pins in the WP-2 hit the edges of the metal parts in female sockets, and no amount of wiggling gets all 38 pins to line up and let the card insert. And trying just risks damaging the pins inside the WP-2. So, the Samtec socket is both deep enough to take the 6mm-long pins, and is manufactured to tight enough tolerances that the pins slot right into the socket with no problems.

### Notes about some of the card slot signals:  

* Pin 2, /DET Card Detect  
  Pin 2 -> RA5 -> IC5 pin 64, "T1"
  
  WP-2 uses this to detect the type of card.  
  The pin is pulled up to VDD inside the WP-2.  
  A RAM card connects this pin to GND, which tells the WP-2 that it is a RAM card.  
  A ROM card leaves this pin not connected, which means it will be pulled high by the pullup resistor inside the WP-2, which tells the WP-2 that it is a ROM card.

* Pin 14, 2nd GND  
  This pin is tied to GND inside the WP-2, but it looks like it's an un-used input or output, not intended to be used as a power gnd.  
  It looks like this pin was partially implimented as Pin 14 -> RA5 -> IC5 pin 65, "T2", just like S1-S3, but ended up not being used in the final production.  
  So instead, IC5 pin 65 is pulled up to VDD and not connected to the socket or anything else, and the connector pin is tied to GND and not connected to anything else.  
  It's possible the "IC Card" spec defines a function for that pin, and the gnd is just a way to satisfy that part of the spec in case there are cards that expect it, like how CE2 is hard-wired to VDD.  
  
  The cards in this repo all include a cuttable solder-jumper to disconnect pin 14 from GND on the card, in case there is some other machine (not WP-2) that might not like the pin being shorted to gnd.

* Pin 3, CE2, active-high chip-enable  
  This is not a real CE2 signal from the WP-2, it's just connected directly to VDD inside the WP-2. The card is only enabled/disabled by /CE1. Some of these designs connect the pin anyway as long as the card is based on a chip that actually has a CE2 pin anyway, because it's possible there is some other machines besides WP-2 that use the same card standard, and possibly one of those might actually use the signal. But for instance the 512K MRAM chip does not have a CE2 pin, and that card does not bother to add logic to impliment it, so the pin is NC on that card.

* Pins 15, 16, & 36  
  
  Pin 15 -> RA5 -> IC5 pin 66, "S1"  
  Pin 16 -> RA5 -> IC5 pin 67, "S2"  
  Pin 36 -> RA5 -> IC5 pin 68, "S3"
  
  RA5 is 100k pullup to VDD.
  
  IC5 is a gate array with unknown programming.
  
  The S1, S2, S3 labels come from a schematic in the service manual. They are not mentioned anywhere else.
  
  The service manual says the original IC Cards have no connections on any of these pins (that's in the cards, not in the WP-2).
  
  It is unknown if the WP-2 does anything at all with these pins.  
  They are connected to a chip, and the chip is a gate array that could be programmed to do anything.  
  The only clues are that the pins are actually connected to anything at all instead of NC, and that they are pulled up rather than down or floating.  
  It suggests there was a possible reserved usage, and that it was an active-low signal, and that possibly software could do it on the existing hardware.  
  One guess for pins 15 & 16 might be made purely from their position on the connector. Possibly the spec for the "Toshiba IC-Card" interface includes pins for A18 and A19 that the WP-2 just doesn't happen to use. Though, unused address lines pins would more likely be pulled down than up, since address lines are active-high.

* Pin 17, A17: Only used for ROM. the WP-2 only supports up to 128K in a RAM card.

* Pin 37, BCHK/Vchk, Battery Voltage Check: It's unknown exactly how this was intended to be used by the "IC-Card" spec.  
  The SRAM card here simply connects pin 37 to BATT+. This seems to do nothing at all on a WP-2 but maybe some other machine like WP-3 or Citizen uses it.  
  The schematic on page 8-2 in the servivce manual doesn't show Vchk connecting to anything, and I also cannot find anything anywhere on the motherboard that has continuity with this pin.  
  Other similar machines did have a pin that was used for the host machine to read the level of the battery on a RAM card.  
  See the VBB pin in [Atari Portfolio Technical reference Guide, page 11](https://archive.org/details/atariportfoliotechnicalreferenceguide1989/page/n10/mode/1up).  

### Other similar machines and card standards that are NOT the same and NOT compatible

The "Toshiba IC-Card" appears to have been just barely almost a standard, maybe, before PCMCIA type 1 was formalized.  
And so it's tempting to try to find other possible cards that might be compatible besides the ones sold by Tandy.  
There might be some but I have not found any yet.

Just for the sake of keeping track somewhere, here are various cards I've found that look very similar, but are NOT the same and NOT compatible.

* Amstrad NC100 and clones & derivatives like NTS DreamWriter 325.  
  They look very similar but the memory card in those is PCMCIA Type 1, which is totally different.

* ITT Canon Star Card  
  Single row 38 pins (or maybe 39 or 40. Pictures all look like 39 holes plus maybe another smaller hole, but references all say 38-pin).  
  But no polarity notch on the pin-38 side.

* Yamaha MCD32 / MCD64  
  This one is evil. It fits perfectly (visually upside down but physically a perfect fit),  
  and shorts VCC directly dead-short to GND, and nothing prevents you from doing it.  

# TODO
* Use the programming adapter to dump ram card images and reverse engineer the "filesystem".  
  The files themselves (at least .DO) are already fairly well documented: https://bitchin100.com/files/wp2/wp2format.html

* Possibly eventually add an mcu to the card that can read & write the sram and present a standard usb mass storage interface to a pc.

* Add a 5v power output for [PDDuino](https://github.com/bkw777/PDDuino)?

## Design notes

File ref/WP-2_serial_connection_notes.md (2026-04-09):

## use telcom as a terminal to login to linux
```
$ sudo stty -F /dev/ttyUSB0 9600 cs8 -parenb -cstopb ixoff ixon -ixany
$ sudo agetty -8 -L ttyUSB0 9600 vt52
```
WP-2: `SETUP` (`F2`+`-`) -> Telcom  
Device: RS232C  
Baud Rate: 9600  
Word Length(bits): 8  
Parity: None  
Stop bits: 1  
XON/XOFF: Enable  
Printer echo: off  
Duplex: Full

## use tpdd emulator to transfer files
`$ dl -v -c wp2` (Ctrl+C to exit)

## run or copy an executable file from disk
* On PC: Start a tpdd emulator
* On WP-2: Press `FILES` (`F2`+`=`) -> `DISKETTE` -> arrows to hightlight foo.PR
  * To run directly from disk: press `RUN` (`F2`+`7`)
  * To copy from `DISKETTE` to `RAM DISK` or `RAM CARD`: press `F1`+`C` or press `HELP` (`F1`+`1`) & select Copy
  * A bug in the system rom truncates run files copied to `MEMORY`.

`MEMORY` = built-in 32k main ram  
`RAM DISK` = optional additional 32k-128k ram installed in option ram socket inside WP-2  
`RAM CARD` = sram IC-card  
`DISKETTE` = TPDD/FB-100 drive or emulator connected to serial port

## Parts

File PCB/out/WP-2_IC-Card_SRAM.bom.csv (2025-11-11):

Reference | Value | Datasheet | Footprint | Qty | DNP | MPN | Description
BT1 | Keystone_3028 | datasheets/M65p9.pdf | 000_LOCAL:Keystone_3028_3034 | 1 |  | Keystone 3028 | SMT 20mm x 1.6mm coin cell holder
C1 | 1u | datasheets/CL21A105KBCLNNC.pdf | 000_LOCAL:C_0805 | 1 |  | CL21A105KBCLNNC | CAP CER 1UF 50V X5R 0805 low profile
C2,C3 | 22u | datasheets/CL31A226MOCLNNC.pdf | 000_LOCAL:C_1206 | 2 |  | CL31A226MOCLNNC | CAP CER 22UF 16V X5R 1206 low profile
D1,D2,D3 | BAV74 | datasheet/BAV74.pdf,datasheets/BAV74.pdf | 000_LOCAL:SOT-23 | 3 |  | BAV74-TP | DIODE ARRAY COMMON CATHODE GP SOT23-3,Dual 100V 215mA high-speed switching diodes, common cathode, SOT-23
J1 | SMS-138-01-S-S | datasheets/sms.pdf | 000_LOCAL:SMS-138-01-x-S_pcb_edge | 1 |  | SMS-138-01-G-S | CONN SKT .050" 38POS
R1,R2,R3,R4 | 100k | datasheets/PYU-RC_GROUP_51.pdf | 000_LOCAL:R_0805 | 4 |  | RC0805FR-07100KL | RES 100K OHM 1/8W 0805
SW1 | CUS-14B | datasheets/cus.pdf | 000_LOCAL:CUS-14TB pth | 1 |  | CUS-14TB | SWITCH SLIDE SP4T 300MA 4V
U1 | AS6C4008 | datasheets/AS6C4008.pdf | 000_LOCAL:TSOP32-dual | 1 |  | AS6C4008-55STIN | 512K x 8 CMOS STATIC RAM, sTSOP I-32, 5V

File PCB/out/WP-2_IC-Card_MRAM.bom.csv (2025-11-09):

Reference | Value | Datasheet | Footprint | Qty | DNP | MPN
C1,C2,C3,C4,C5,C6,C7,C8,C9,C10,C11,C12 | 1u | datasheets/CL21A105KBCLNNC.pdf | 000_LOCAL:C_0805 | 12 |  | CL21A105KBCLNNC
D1 | BAW56 | datasheets/BAW56.PDF | 000_LOCAL:SOT-23 | 1 |  | TBAW56,LM
J1 | SMS-138-01-G-S | datasheets/sms_th.pdf | 000_LOCAL:SMS-138-01-x-S_pcb_edge | 1 |  | SMS-138-01-G-S
R1,R2,R3,R4,R5 | 200k | ~ | 000_LOCAL:R_0805 | 5 |  | RMCF0805FT200K
SW1 | CUS-14B | datasheets/cus.pdf | 000_LOCAL:CUS-14TB pth | 1 |  | CUS-14TB
U1 | MRxA08xxYSxxx | datasheets/MR2A08A.pdf | 000_LOCAL:TSOP-II-44_10.16x18.41mm_P0.8mm | 1 |  | MR2A08ACYS35
U2 | MIC5318-3.3YD5 | datasheets/MIC5318.pdf | 000_LOCAL:TSOT-23-5 | 1 |  | MIC5318-3.3YD5
U3,U4,U5,U6 | LVCH8T245 | datasheets/LVCH8T245.pdf | 000_LOCAL:TSSOP-24_4.4x7.8mm_P0.65mm | 4 |  | 74LVCH8T245PW,118

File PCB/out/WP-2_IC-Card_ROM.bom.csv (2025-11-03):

Reference | Value | Datasheet | Footprint | Qty | DNP | MPN | Description
C1 | 1u | datasheets/CL21A105KBCLNNC.pdf | 000_LOCAL:C_0805 | 1 |  | CL21A105KBCLNNC | CAP CER 1UF 50V X5R 0805 low profile
J1 | SMS-138-01-S-S | datasheets/sms.pdf | 000_LOCAL:SMS-138-01-x-S_pcb_edge | 1 |  | SMS-138-01-S-S | 01 x 13 x 1.27mm pitch female
R1 | 100k | datasheets/PYU-RC_GROUP_51.pdf | 000_LOCAL:R_0805 | 1 |  | RC0805FR-07100KL | RES 100K OHM 1/8W 0805
SW1 | CUS-13B | datasheets/cus.pdf | 000_LOCAL:CUS-13B special | 1 |  | CUS-13TB | Switch, 3 position, single pole 3 throw, 3 position switch, SP3T
SW2 | CUS-12B | datasheets/cus.pdf | 000_LOCAL:CUS-12TB pth | 1 |  | CUS-12TB | Switch, 2 position, single pole 2 throw, 2 position switch, SPDT
U1 | 29F0x0 | datasheets/29F0x0.pdf | 000_LOCAL:TSOP32-dual | 1 |  | SST39SF040-70-4C-TU | 64K 128K 256K 512K x 8 FLASH/EEPROM

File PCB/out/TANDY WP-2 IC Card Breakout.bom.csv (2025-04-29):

Reference | Value | Datasheet | Footprint | Qty | DNP | MPN
J1 | SMS-138-01-G-S | ~ | 000_LOCAL:SMS-138-01-x-x_pcb_edge | 1 |  | SMS-138-01-G-S
J2 | Conn_02x19_Odd_Even_PCB_Edge | ~ | 000_LOCAL:Pin-Header_2x19_P2.54mm_PCB_Edge | 1 |  | PRPC019DAAN-RC

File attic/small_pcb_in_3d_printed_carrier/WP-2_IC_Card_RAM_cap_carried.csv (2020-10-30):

Index | Quantity | Part Number | Manufacturer Part Number | Description | Customer Reference | Available | Backorder | Unit Price | Extended Price USD
1 | 1 | SMS-138-01-G-S-ND | SMS-138-01-G-S | CONN SKT .050" 38POS |  | 1 | 0 | 6.96000 | 6.96
2 | 1 | 706-1042-ND | IS62C1024AL-35TLI | IC SRAM 1M PARALLEL 32TSOP I |  | 1 | 0 | 1.75000 | 1.75
3 | 1 | 311-47.0KCRCT-ND | RC0805FR-0747KL | RES SMD 47K OHM 1% 1/8W 0805 |  | 1 | 0 | 0.10000 | 0.10
4 | 1 | 1SS389L3FCT-ND | 1SS389,L3F | DIODE SCHOTTKY 10V 100MA ESC |  | 1 | 0 | 0.20000 | 0.20
5 | 1 | YAG3738CT-ND | AC0805FR-074K7L | RES SMD 4.7K OHM 1% 1/8W 0805 |  | 1 | 0 | 0.10000 | 0.10

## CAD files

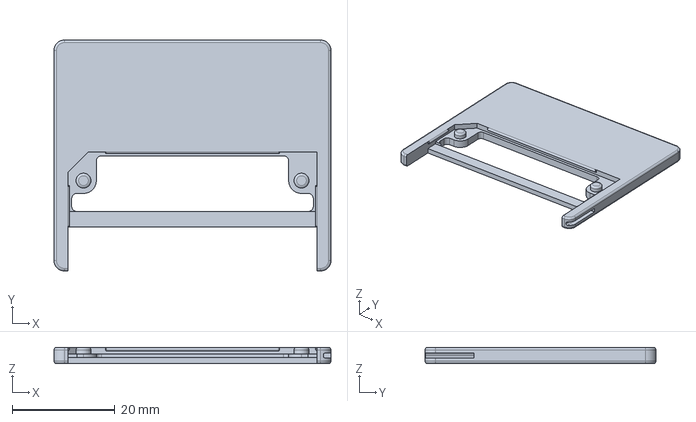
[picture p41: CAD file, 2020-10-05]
attic/small_pcb_in_3d_printed_carrier/Carrier/WP-2_IC_Card_Carrier_v003.step
54.0 x 45.0 x 3.20 mm

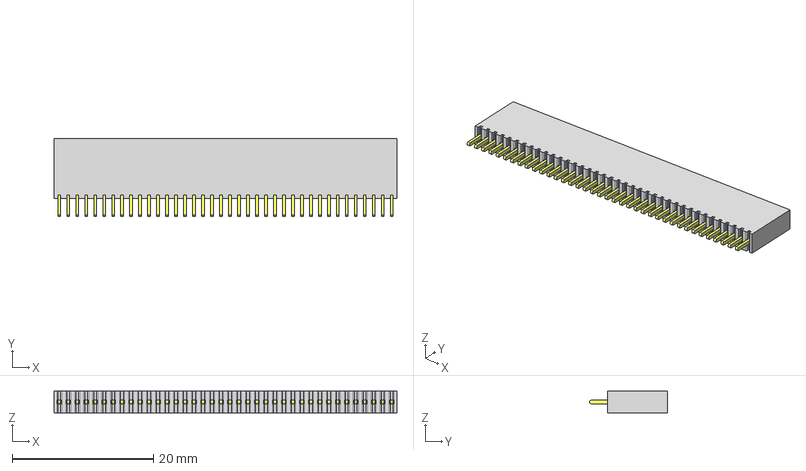
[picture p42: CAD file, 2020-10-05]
attic/small_pcb_in_3d_printed_carrier/PCB/3d/SMS-138-01-x-x.stp
48.5 x 11.0 x 3.05 mm
_SMS-138-01-S_socket
_C-16-01-38-S

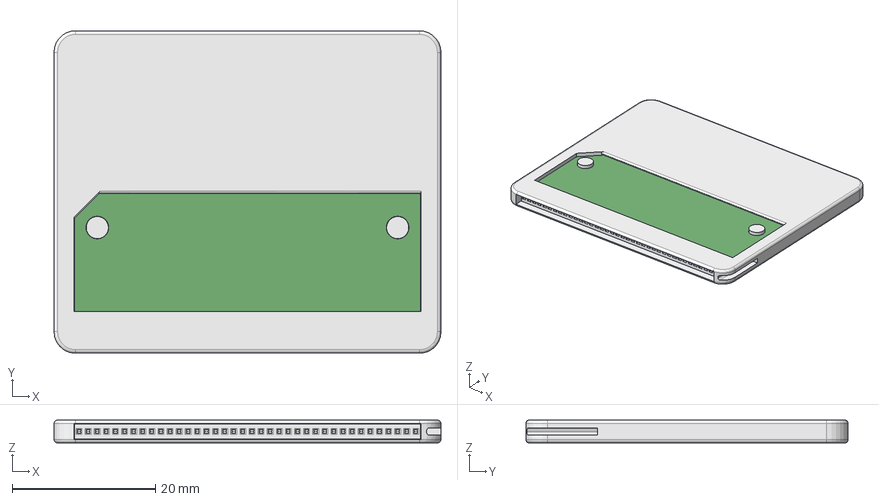
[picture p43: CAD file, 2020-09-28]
Carrier/WP-2_IC_Card.FCStd
54.0 x 45.0 x 3.20 mm
CARRIER

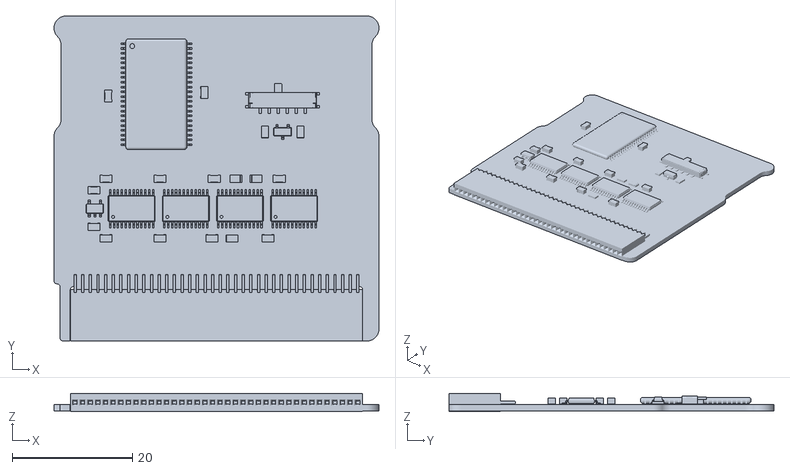
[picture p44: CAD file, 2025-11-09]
COVER/inc/MRAM.pcb.stl
54.0 x 54.0 x 3.05

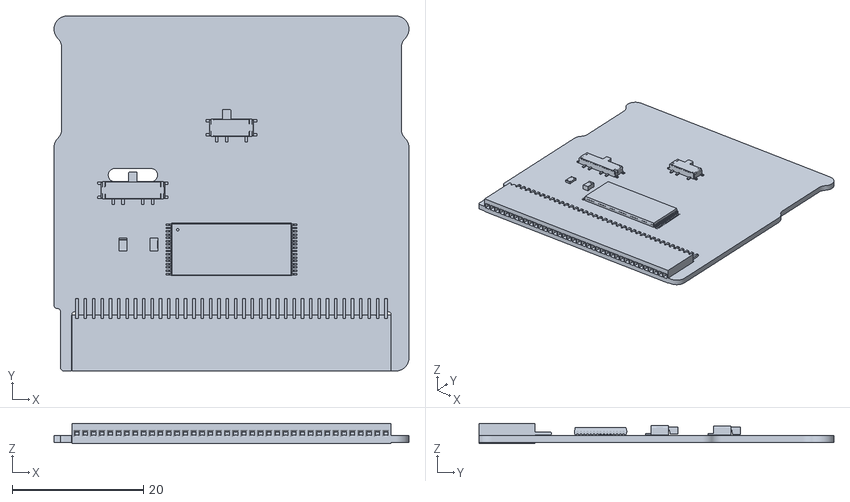
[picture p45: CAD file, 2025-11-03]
COVER/inc/ROM.pcb.stl
54.0 x 54.0 x 3.05

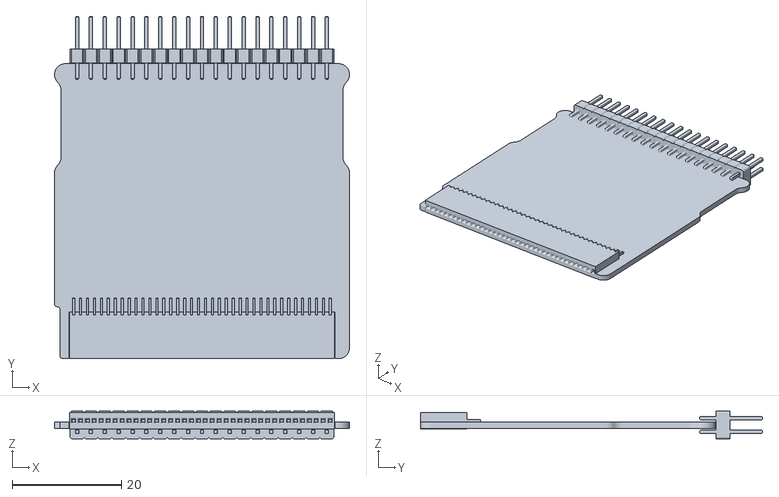
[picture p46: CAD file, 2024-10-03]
COVER/inc/breakout.pcb.stl
54.0 x 62.7 x 5.08

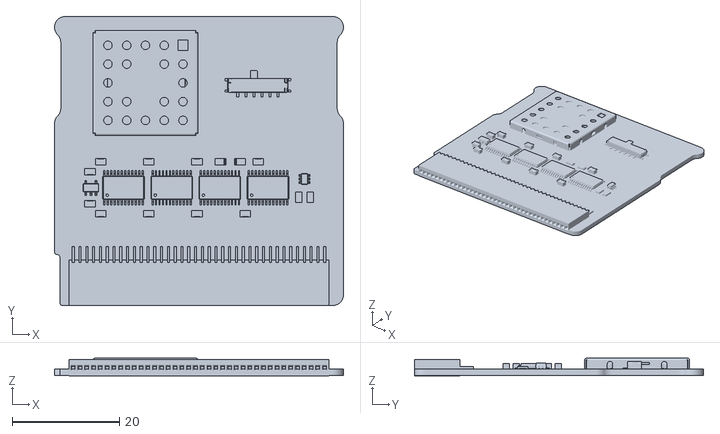
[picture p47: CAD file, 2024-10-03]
COVER/inc/mram-shielded.pcb.stl
54.0 x 54.0 x 3.33

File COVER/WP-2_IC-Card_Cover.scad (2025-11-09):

// top cover for WP-2 IC Card
//
// Generates several different possible parts.

// Mostly you shouldn't need to edit these variables directly.
// Use the customizer panel to output variations without changing the code.

// Render in print orientation, else render in preview orientation
PRINT = true;

// Which part to generate?
part = "SRAM"; // ["SRAM","MRAM","ROM","breakout","bottom"]
// "SRAM"        top cover for the SRAM card
// "ROM"         top cover for the FLASH card
// "MRAM"        top cover for the MRAM card
// "breakout"    top cover for the breakout card
// "bottom"      bottom cover - thickness is determined indirectly from pcb_thickness, 1.2mm pcb leaves 0 bottom cover
// "slider_2p"   just the bank switch actuator slider part by itself, 2-position
// "slider_3p"   just the bank switch actuator slider part by itself, 3-position
// "slider_4p"   just the bank switch actuator slider part by itself, 4-position
// "wren_slider" just the write-enable switch actuator slider part by itself, it's narrower than normal

// Which style of slide switch actuator?
// Use "none" to delete a switch.
// IE for a 128K card with no bank switch installed,
// you can output a cover with no opening or slider.
//
// "slider"  trapped sliding actuator
// "finger"  large concave opening for a finger
// "pen"     minimal slot for pen
// "under"   slot in pcb, top is covered
// "none"    switch not populated, delete from cover
// "solder"  switch not populated, but there is a solder-blob

// bank switch for SRAM / MRAM
ram_bank_switch_style = "finger"; // ["finger","slider","pen","under","none"]
// bank switch for ROM
rom_bank_switch_style = "none"; // ["finger","slider","pen","under","none"]
// write-enable switch for ROM
wren_switch_style = "under"; // ["under","solder","slider","pen","finger"]


///////////////////////////////////////////////////////////////////////////////////
///////////////////////////////////////////////////////////////////////////////////


// "pen" switch style slot width
pen_slot_width = 3;

// bank switch slider width
bank_slider_width = 6;
// bank switch finger width - make it wide enough to see the labels
bank_finger_width = 6;

// write-enable switch slider width
wren_slider_width = 3;
// write-enable switch finger width
wren_finger_width = 4;

// You want this as small as you can successfully print.
// 1.0 = 45 degrees. Easy to print but annoying to use.
// 0.5 or less is nice to use but difficult to print overhang. 
// The slope of the chamfer for switches with "finger" style opening. 1.0=45 deg.
finger_chamfer_slope = 0.6;
finger_window_chamfer_slope =
  (finger_chamfer_slope<0.2)?0.2:
  (finger_chamfer_slope>100)?100:
  finger_chamfer_slope;


///////////////////////////////////////////////////////////////////////////////////


// attach the slider to the main body with sprues
attach_slider = false;
sprue_len = 2;

// preview display option
// override default and show the switch slider in arbitary switch position #
// value is switch position number, ie 4 position switch values are 1, 2, 3, 4
//
// preview switch position - only for slider
ram_bank_switch_slider_position = 3;
rom_bank_switch_slider_position = 2;
// preview switch position - only for slider
wren_switch_slider_position = 1;


// card_thickness is the total stack thickness
// of the pcb, printed parts, and adhesives, above and below.
//
// The original cards are 3.2mm, so card_thickness may go up to 3.2.
// But because of the way our connector has to work,
// anything over 3.0mm moves the connector off center vertically,
// (the cover becomes taller than the body of the connector)
// and that causes the pins to bind up.
//
// You could increase this to 3.1,
// and add a layer of packing tape on the bottom.
// End result is 3.2 total, with the connector still centered,
// and the bottom pcb traces protected from scratches and shorting.
//
//card_thickness = 2.8; // 2.8, 2.9, make the top cover thinner
// to leave room to apply a sheet on top like cut vinyl
// to cover over the openings on top. Perhaps laser cut steel
// to provide magnetic shielding for the MRAM?
//
//card_thickness = 3.0; // 3.0 default - use this for 1.2mm PCB thickness and no bottom cover
//card_thickness = 3.1; // *** 3.1, 3.2 make the top slightly thicker to make room for the 0.7 thin_wall_minimum
//
// Lately I'm using the full 3.2 here
// and letting adhesive_thickness make it thinner instead.
// That *technically* makes all the component pockets slightly
// short but in reality it works fine, and allows the model
// to have a thick enough ceiling for SLS printing.

// Total stackup thickness of all parts: bottom cover + pcb + adhesive + top cover: spec is 3.2
card_thickness = 3.2;

// If pcb_thickness is less than 1.2, then generate a bottom cover too.
// If you put 0.8 here to generate a bottom cover,
// then change card_thickness to 3.2 also,
// so that the bottom cover is as thick as possble.
// If using 1.2mm pcb, then leave card_thickness at 3.0 for better centering of the connector in the slot.
// 0.8 or 1.2 are the only really useful values, even though pcbs can be ordered in other thicknesses.
// You can order a 1.0mm pcb, and that could be useful because you could cover the bottom with tape or cut vinyl,
// but it's not useful *here* because a bottom cover generated from here will be too thin to be printed.
//pcb_thickness = 0.6;
//pcb_thickness = 0.8;

// default 1.2, may be thinner but no thicker. If less than 1.2, possible to add bottom cover.
pcb_thickness = 1.2; // ***

// How tall is the tallest component? (not counting the battery holder or slide switch)
// If this is any greater than 1.2, then there will be no roof over the components.
// It still protects the components and fills the slot so the card doesn't wobble,
// it's just cosmetically nicer to have a solid top surface.
// The sram and diode are 1.2mm, and the resistors are usually under 1.0,
// The only question is the caps. When sourcing components you have to specifically
// select caps that are 1.2mm or less, most will be a little taller.

// height of tallest component - really 1.2 but fudge it down to 1.15 to allow thin_wall_minimum over top
components_height = 1.2; // .01

// If card_thickness - pcb_thickness - components_height 
// comes out less than thin_wall_minimum, then don't
// try to print the roof over the components (too thin).
// Also affects how thin the battery retainer bridge
// is allowed to get. Unlike the components cover, it will
// always print the feature, but won't let the other
// constraints make it any thinner than this.
// Does not affect the bottom cover part. That part is always thin.
// FDM can theoretically print as thin as a single layer. 0.12mm or even less,
// at least for the first layers right on the bed.
// Commercial SLS services usually specify a minimum allowed wall thickness of 0.7mm
// With card_thickness = 3.0,
// minus pcb_thickness = 1.2,
// minus components_height = 1.2,
// there isn't 0.7mm left above the components.
// Set this to 0.7 to generate a model that can be printed by SLS or MJF.
// Set this to 0.6 or less if you want to try covering all components
// including extra thin parts over tall components like the slide swtch.
//thin_wall_minimum = 0.3; // 0.3 FDM printing, slide switch only has 0.3mm above it.
//thin_wall_minimum = 0.6; // *** 0.6 FDM printing (home)
// Commercial SLS/MJF usually cannot print below = 0.7-0.8. FDM at home can be as low as a single layer. If the ceiling over a component pocket will be less than this, then a hole is punched clean through instead. For printing your own on FDM you can set this to 0.5 or less to cover even the tops of the slide switches.
thin_wall_minimum = 0.8; // 0.01

// For liquid glue, use 0.
// For thin adhesive transfer tape, use 0 to 0.2
// amazon.com/dp/B06Y34587N 3M 468MP 5.2mil is 0.13mm

// Shaves the bottom of the top cover to make room for adhesive without making the card thicker
adhesive_thickness = 0.2; // 0.01

// The solder posts on the main connector. True size is 0.51 . Padded to account for a slight discrepency between the pcb thickness and the plastic body of the connector, to make the top_thickness come out to 2.0 (3.2 total - 1.2 pcb), so that we can actually use the available 0.8mm for wall thickness over top of the components.
connector_post_thickness = 0.8; // 0.01

// add a little more vertical height to the pocket above the slider to allow the top cover to come down closer than adhesive_thickness without binding up the slider
slider_extra_clearance = 0.1; // 0.01
// add a little more throw length to the slider slot
slider_extra_throw = 0.1; // 0.01
slider_fingernail_depth = 0.8;

battery_tunnel_roof_thickness = 0.8;

//// Some useful combinations:

// SLS
// Add a layer of packing tape to cover the bottom of the PCB
// Total card thickness with the tape is 3.2mm
//card_thickness = 3.1;
//pcb_thickness = 1.2;
//thin_wall_minimum = 0.7;
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

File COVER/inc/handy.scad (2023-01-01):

// b.kenyon.w@gmail.com - handy box
// fillets and handy things made from fillets

/*
   screw_post(h=10,od=6,id=3,fr=2,ch=0,o=0)

     cylindrical screw post with filleted base

     h = height
     od = main cylinder OD
     id = screw hole ID - default no hole
     fr = base fillet radius
     ch = screw hole chamfer depth - default no chamfer
     o = fillet ID shrink offset - usually unset

   rounded_cube(w=60,d=40,h=20,rh=2,rv=1,t=0)

     draws a cube with rounded corners

     w = width
     d = depth
     h = height
     rh = horizontal radius
     rv = vertical radius
     t = wall thickness - if set, makes a hollow box

   fillet_polar(o=false,R=1,r=1,A=90,a=90,as=0)

     creates both internal and external radial fillets
     used to create screw_post() and rounded_cube()
  
     o = outside true/false - default false (inside/concave)
     R = big radius
     r = small radius
     A = big angle
     a = small angle
     as = small angle start angle

   fillet_linear(o=false,l=1,r=1,a=90)
   
     o = outside - true/false - default false (inside/concave)
     l = length
     r = radius
     a = angle

*/

//$fs = 0.5;
//$fa = 1;
//$fn = 96;
//$fn = 72;
//$fn = 36;
//$fn = 12;

// examples:
//translate([60,0,0]) screw_post(h=10,od=6,id=3,fr=2,ch=0.6);
//difference() { rounded_cube(w=70,d=55,h=25,rh=3,rv=1,t=2); translate([0,-40,0]) cube([40,40,20]); }
//difference() { rounded_cube(w=70,d=55,h=25,rh=3,rv=1); translate([0,-40,0]) cube([40,40,20]); }
//fillet_linear(l=40);
//fillet_polar(R=2,r=1);

module screw_post(h=10,od=6,id=0,fr=2,o=0,ch=0) {
 x = (o) ? o : ($fn>=3) ? 0 : 0.025;
 difference() {
  union(){
   translate([0,0,h/2]) cylinder(h=h,d=od,center=true);
   translate([0,0,fr+x]) fillet_polar(R=-od/2+x,r=fr+x,A=360,as=90);
  }
  if(id>0) {
   translate([0,0,h/2]) cylinder(h=h+0.1,d=id,center=true);
   if(ch) translate([0,0,h-id/2-ch]) cylinder(h=od/2,d1=0,d2=od);
  }
 }
}

module rounded_cube(w=60,d=40,h=20,rh=2,rv=1,t=0) {
  if(t) difference() {
   _hbrc(w=t+w+t,d=t+d+t,h=t+h+t,rh=rh+t,rv=rv+t);
   _hbrc(w=w,d=d,h=h,rh=rh,rv=rv);
  }
  else _hbrc(w=w,d=d,h=h,rh=rh,rv=rv);
}

module _hbrc(w=60,d=40,h=20,rh=2,rv=1) { // rounded cube
 hull() {
  mirror_copy([0,0,1])
   mirror_copy([0,1,0])
    mirror_copy([1,0,0])
     translate([w/2-rh,d/2-rh,h/2-rv])
      fillet_polar(o=true,R=rh,r=rv);
 }
}

module fillet_polar(o=false,R=1,r=1,A=90,a=90,as=0) {
 rotate_extrude(angle=A)
  translate([R-r,0,0])
   rotate([0,0,-as])
    _hbf(o,r,a);
}

module fillet_linear(o=false,l=1,r=1,a=90) {
 //linear_extrude(height=l,center=false)
 linear_extrude(height=l)
  _hbf(o,r,a);
}

module _hbf(o=false,r=1,a=90) { // 2d fillet
 if(o) intersection() { circle(r=r); _hbw(r=r,a=a); }
 else difference() { _hbw(r=r,a=a); circle(r=r); }
}

module _hbw (r=1,a=90) { // 2d wedge polygon
  polygon([ [0,0], [0,r], [r*tan(a/2),r], [r*sin(a),r*cos(a)] ]);
}

module mirror_copy(v) {
 children();
 mirror(v) children();
}

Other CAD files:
COVER/inc/SRAM.pcb.stl
attic/small_pcb_in_3d_printed_carrier/Carrier/WP-2_IC_Card_Carrier_v003.stl

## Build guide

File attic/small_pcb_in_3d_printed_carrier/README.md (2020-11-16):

# Expansion IC Card for TANDY WP-2

The TANDY WP-2 has an expansion slot that accepts "IC Cards" that may be either RAM or ROM, up to 128K RAM, up to 256K ROM. Here are a few different types of cards to fit that slot. So far, one RAM and one ROM in the form of a small pcb that snaps into a 3d-printed carrier, and one RAM and one ROM in the form of a large pcb with no carrier. The large RAM card includes a battery backup.

All but the programming adapter must be thinner PCBs than the standard 1.6mm.  
The small cards that fit in the 3d-printed carrier must be 0.8mm thick.  
The large RAM card with the coin cell battery holder may be up to 1.0mm thick.  
The large ROM card may be up to 1.2mm thick.  

## Status: 2020-11-15  

<B>The RAM cards are verified working.</B>  
There are some notes though.

The only really useful RAM card is the one with the battery. RAM that dies the instant you turn the power off or RAM that dies within 10 minutes of power-off or ejecting, is not good for much.

Supporting this opinion, the advertisements for the original 32K RAM cards from TANDY said they were battery-backed.

So, I suggest it probably doesn't make any sense to even mess with the RAM card that uses the 3d-printed carrier, because it only has a capacitor for a about 10 minutes of protection. It saves you from bumps and accidents and brief power-off, but no more. If I can't come up with a way to get a battery into that style of card, I may just remove that version of the card just to keep things simpler. Too bad because the 3d-printed carrier is nice. :/

However the current design for the battery-backed card uses diodes that are SUPER TINY. They are ridiculous to try to solder manually. Not just because they are so tiny. The even worse problem is that you can't see the polarity marking on the top, even with magnification, it's just too faint. With a lot of light and magnification you can just barely sort of maybe guess which direction is right. So it's very annoying to have to actually test the diodes with a meter to get the polarity and then make sure you install them the right way by just keeping an eye on them and remembering which way you set them down. I need to find a larger package diode that still has the lowest possible forward voltage.

You CAN safely buy the parts and order the pcb for this design as of now, if you are OK with dealing with those diodes. The electrical design is at least verified and working.

<B>The ROM cards are NOT verified working yet.</B>  
The pinout between the chip and the slot looks correct, and the programming adapter looks correct, but my initial test with the programming adapter isn't working. At this point, it might actually just be a bad flash chip or a bad soldering job or something else, and the the pcb design might actually be good, it just isn't *proven* yet.

## RAM CARDS

### RAM_cap_carried
RAM card with optional memory power capacitor, small pcb in a 3d-printed carrier.

You may build this two ways:  

Basic: Don't install any components other than the SRAM chip and pin socket. Solder-bridge the D1/SB1 footprint.

Full: Install all components, including a diode on D1/SB1.

Full configuration provides about 10 minutes of memory power from a capacitor while the card is ejected or the WP-2 power is off.

Requires a thinner PCB than normal.  
This PCB may be up to 0.8mm thick.  

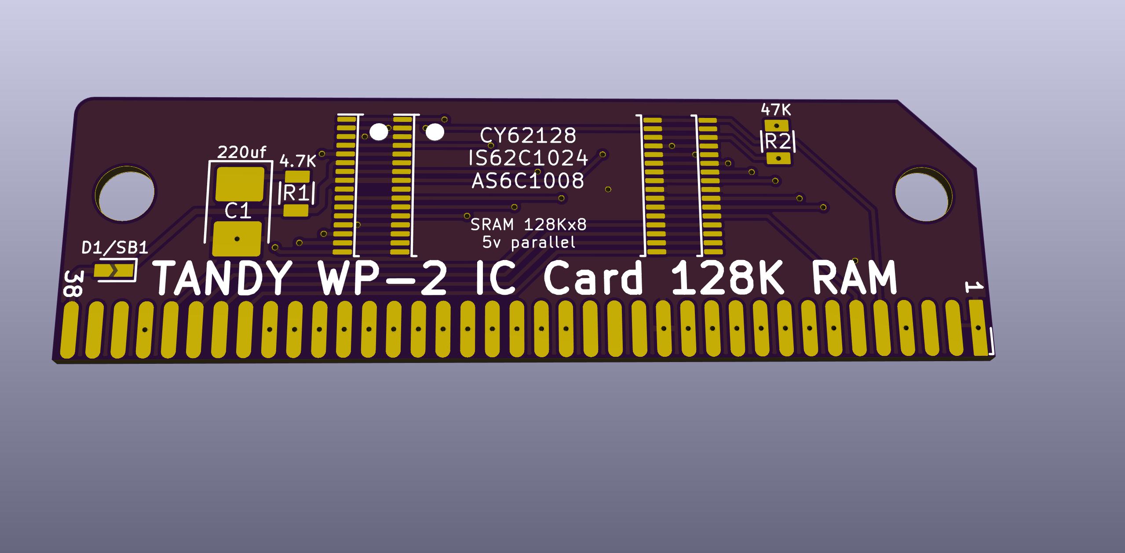
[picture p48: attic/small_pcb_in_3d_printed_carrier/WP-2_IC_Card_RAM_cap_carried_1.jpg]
  
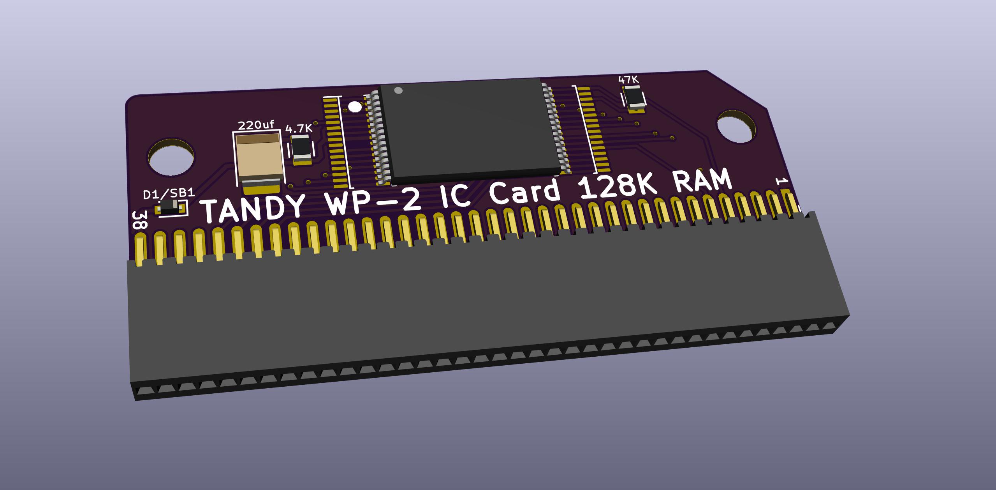
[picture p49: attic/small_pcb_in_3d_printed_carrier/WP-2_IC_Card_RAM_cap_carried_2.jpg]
  
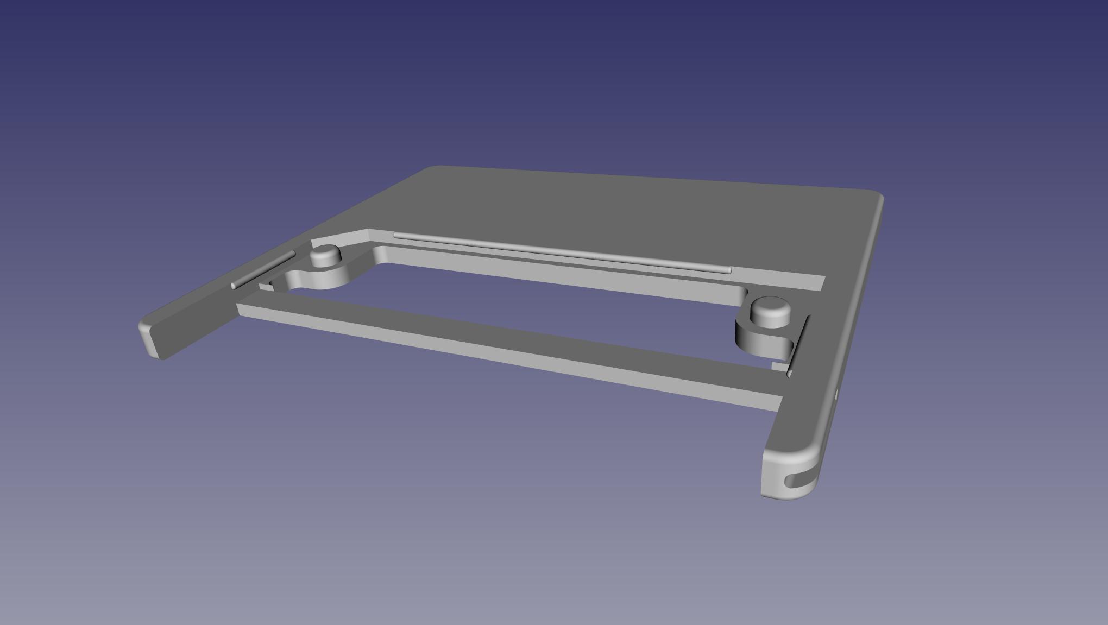
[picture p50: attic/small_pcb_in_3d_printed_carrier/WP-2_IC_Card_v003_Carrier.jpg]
  
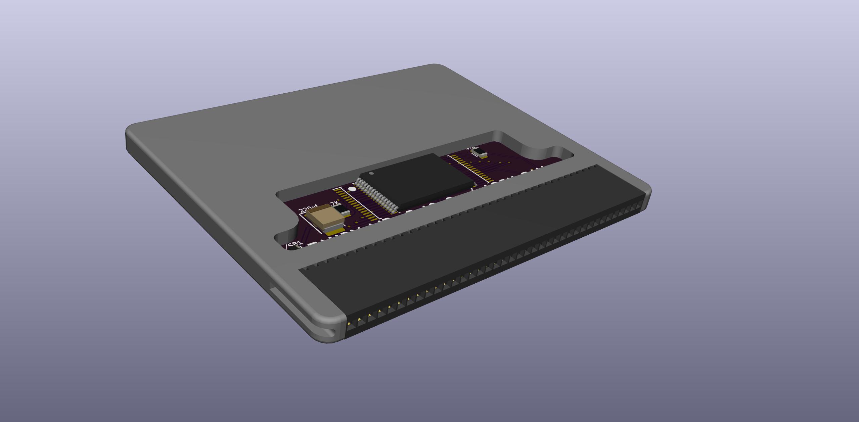
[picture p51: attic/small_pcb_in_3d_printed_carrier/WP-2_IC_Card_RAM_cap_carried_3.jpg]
  
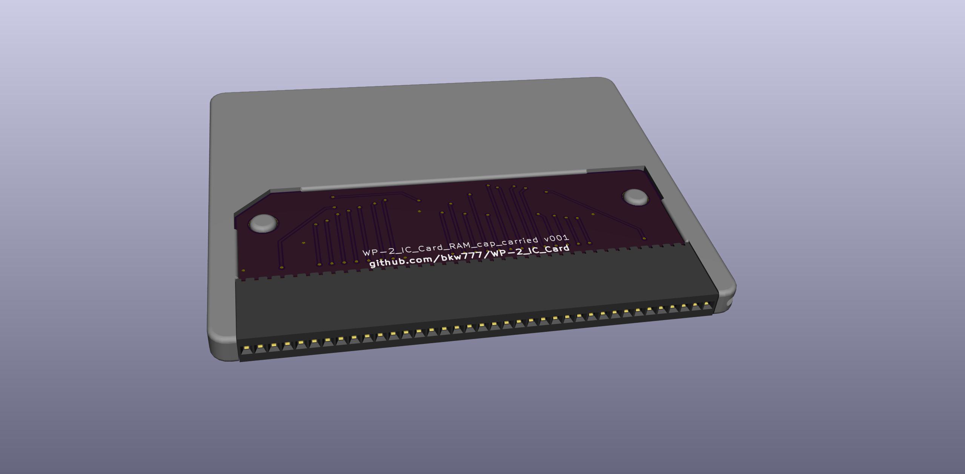
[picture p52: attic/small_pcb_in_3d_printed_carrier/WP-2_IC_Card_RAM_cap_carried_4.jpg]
  
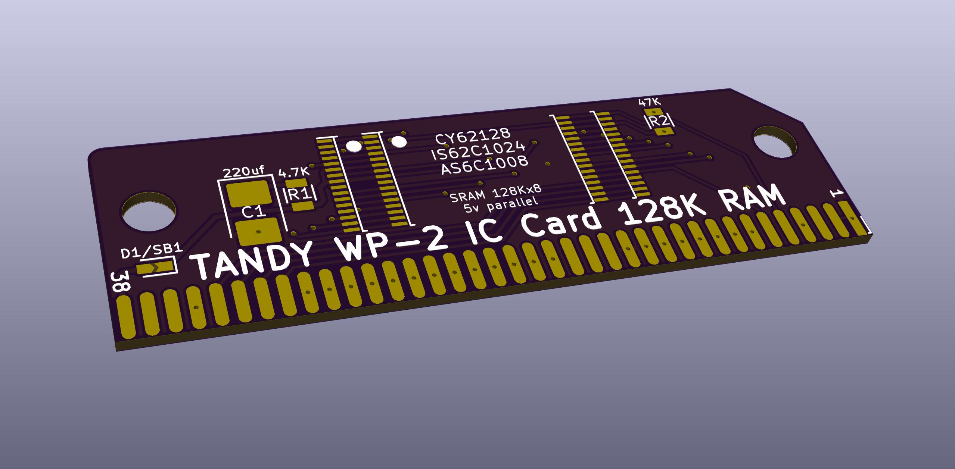
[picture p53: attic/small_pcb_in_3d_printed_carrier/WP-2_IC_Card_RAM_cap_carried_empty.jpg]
  
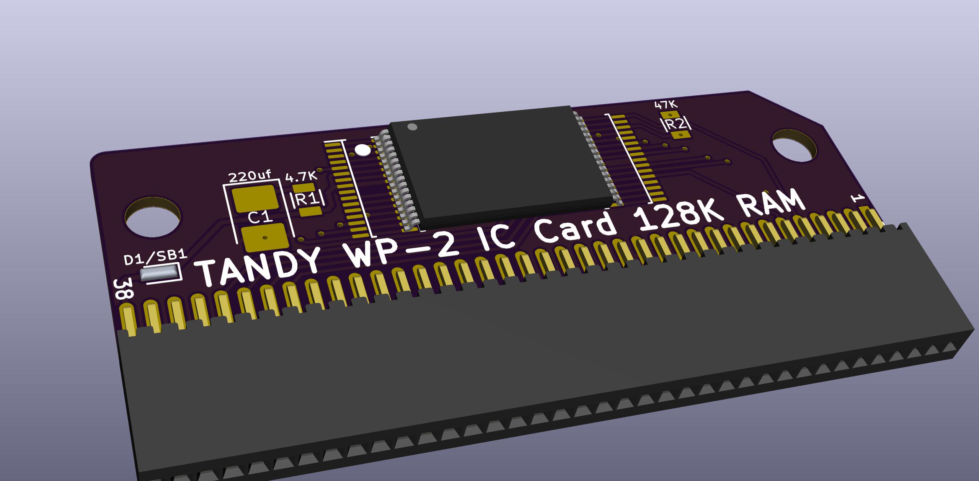
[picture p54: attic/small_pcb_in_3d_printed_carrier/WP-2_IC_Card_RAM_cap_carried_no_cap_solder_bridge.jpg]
  
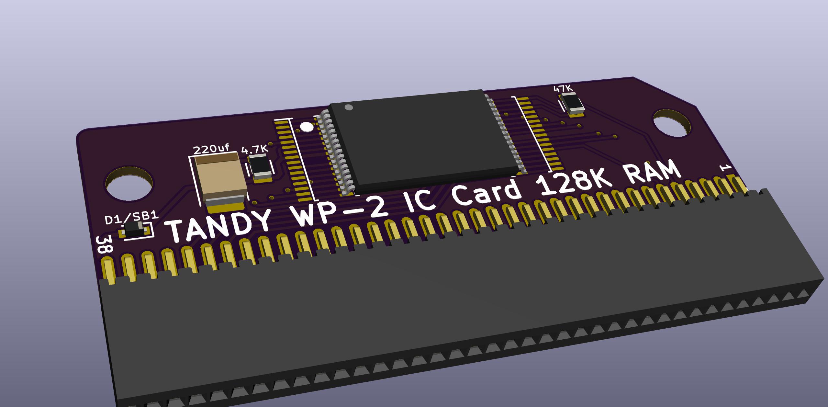
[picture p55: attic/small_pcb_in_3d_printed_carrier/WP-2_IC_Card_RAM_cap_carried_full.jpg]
  
  

CARRIER  (RAM and ROM versions both use this same carrier)  
[Carrier v003 at Shapeways](https://shpws.me/Si2L)  

PCB  
[PCB RAM_cap_carried at OSHPark](https://oshpark.com/shared_projects/ElSkz5po) (Select 0.8mm pcb thickness at checkout)  

BOM  
[Parts for RAM_cap_carried from DigiKey](https://www.digikey.com/short/zdp7q1)

### RAM_cap_batt_no_carrier
RAM version with optional battery and no 3d-printed carrier.  

You may build this 4 ways:

Basic: Don't install any components other than the SRAM chip and pin socket. Solder-bridge the D1/SB1 footprint.  
Memory is lost immediately when the card is ejected or the WP-2 is turned off.

With cap, no battery: Install C1, R1, R2, and diode on D1/SB1.  
Provides about 10 minutes of memory power.

With battery, no cap: Install battery holder, D2, R2, and diode on D1/SB1.  
Provides about 10 years of memory power, but only while the battery remains connected. Memory is lost immediately if battery is removed.

Full: Install all components, including diode on D1/SB1.
Provides about 10 years of memory power, and about 10 minutes of memory power without the battery.

Requires a thinner PCB than normal.  
This PCB may be up to 1.0mm thick.  

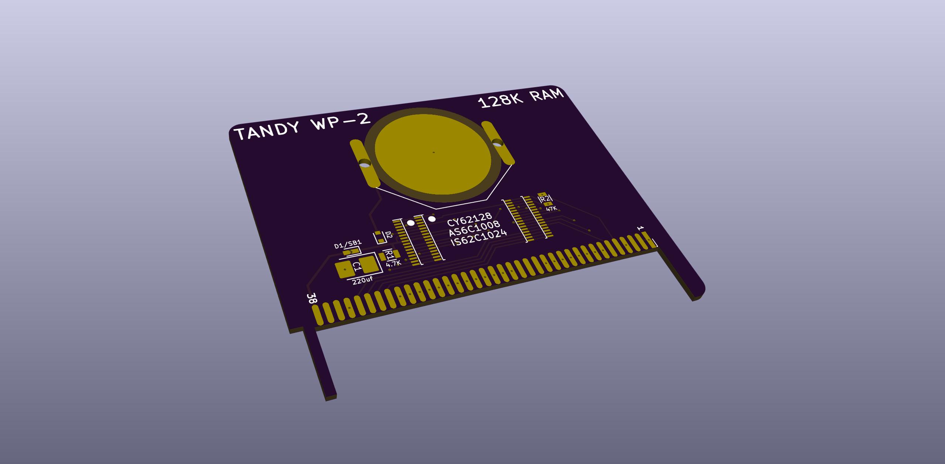
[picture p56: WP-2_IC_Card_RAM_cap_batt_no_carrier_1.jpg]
  
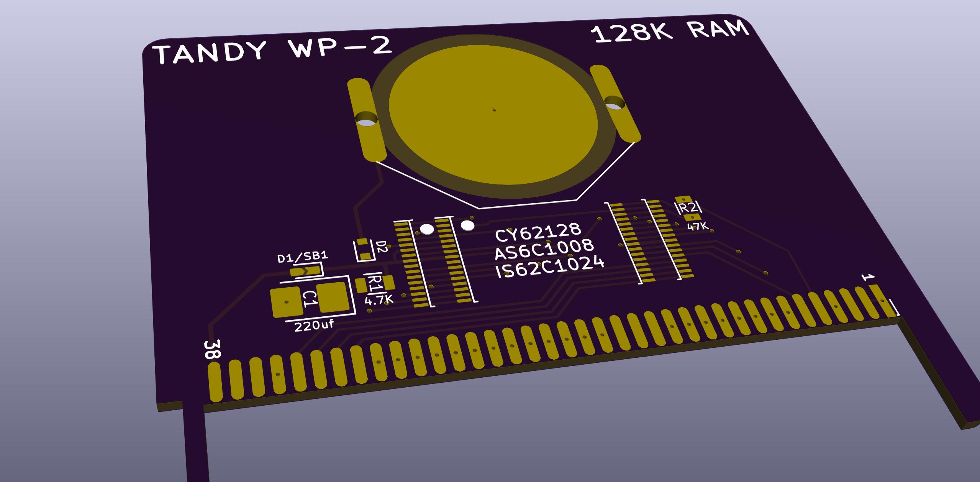
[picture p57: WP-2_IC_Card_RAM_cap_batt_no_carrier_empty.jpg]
  
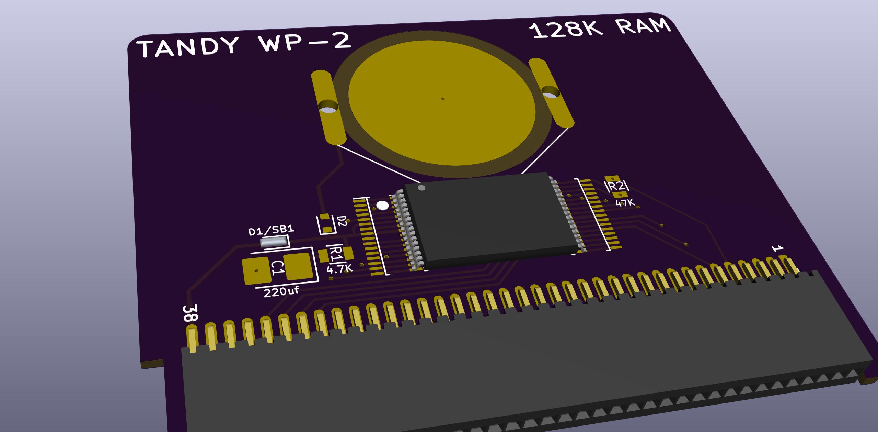
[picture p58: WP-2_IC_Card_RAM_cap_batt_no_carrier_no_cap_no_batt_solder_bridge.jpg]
  
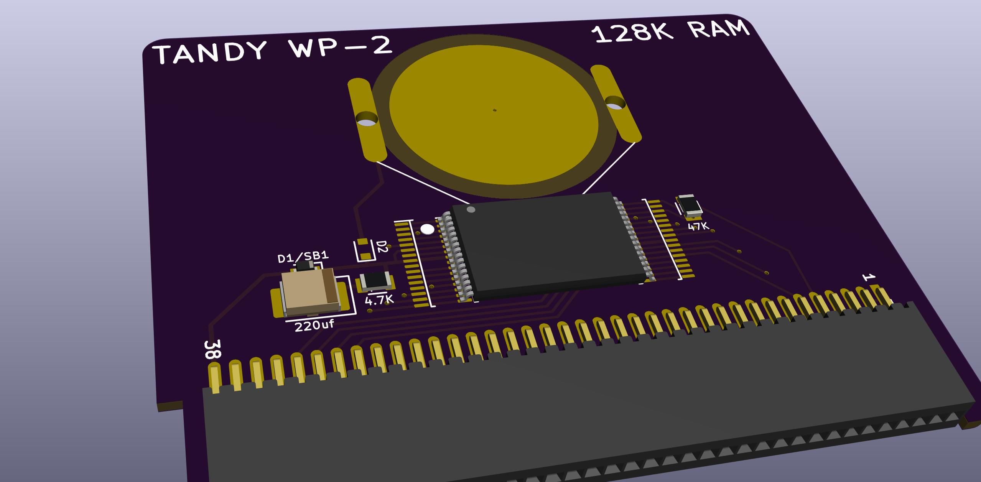
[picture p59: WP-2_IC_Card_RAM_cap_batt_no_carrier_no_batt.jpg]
  
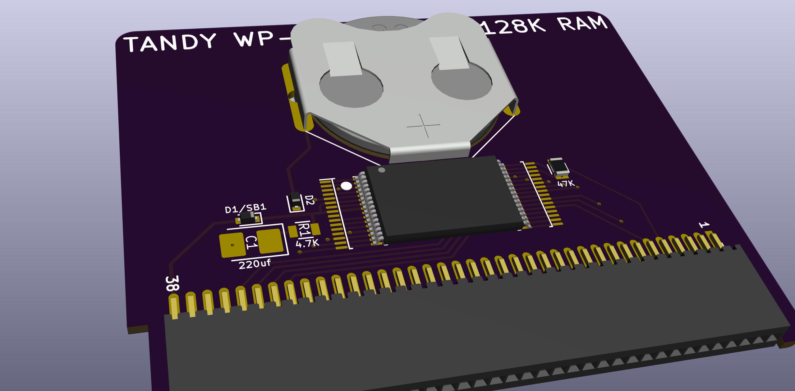
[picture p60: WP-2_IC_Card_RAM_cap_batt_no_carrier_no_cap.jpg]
  
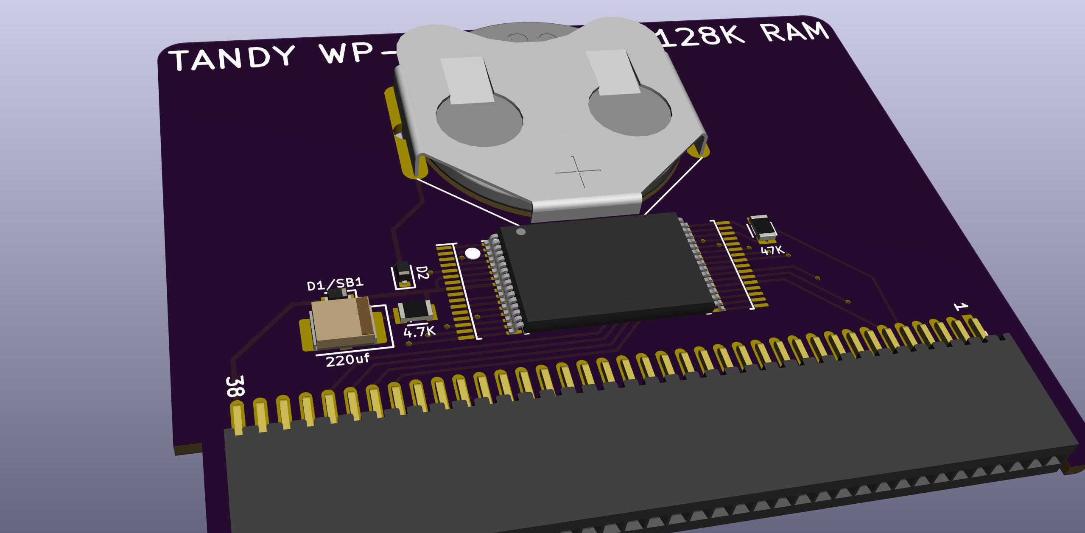
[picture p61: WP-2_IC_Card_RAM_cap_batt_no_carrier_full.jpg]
  
  

PCB  
[PCB RAM_cap_batt_no_carrier at OSHPark](https://oshpark.com/shared_projects/eNruwuT6) (Select 0.8mm pcb thickness at checkout)  

BOM  
[Parts for RAM_cap_batt_no_carrier at DigiKey](https://www.digikey.com/short/zn0wrr)

## ROM CARDS

### ROM_carried
"ROM" based on a flash chip, which may be written using a matching programming adapter and standard eprom burner.

Requires a thinner PCB than normal.  
This PCB may be up to 0.8mm thick.  

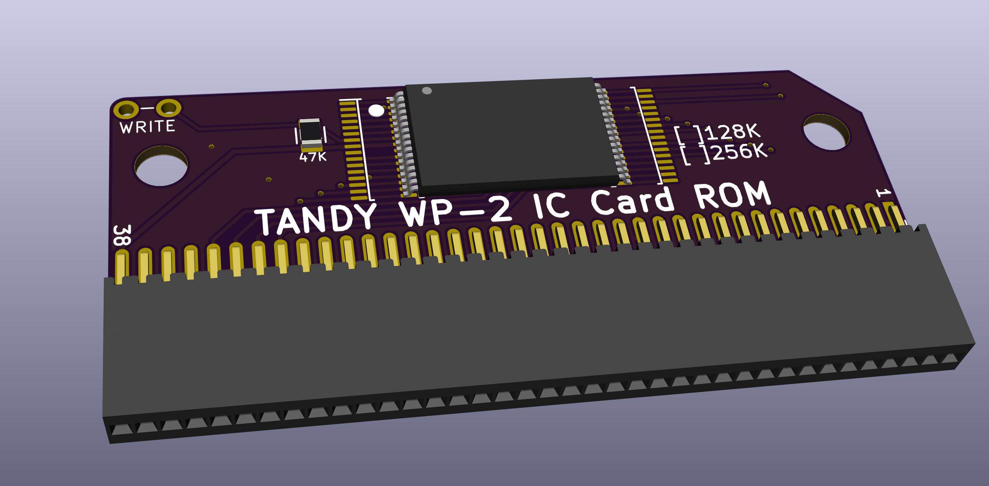
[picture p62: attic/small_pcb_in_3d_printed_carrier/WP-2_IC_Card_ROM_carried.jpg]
  
  

PCB  
[PCB ROM_carried at OSHPark](https://oshpark.com/shared_projects/zKWT2O4v) (Select 0.8mm pcb thickness at checkout)  
[PCB ROM_carried at PCBWAY](https://www.pcbway.com/project/shareproject/WP_2_IC_Card__256K_ROM__carried.html) (Select 0.8mm pcb thickness at checkout)  

BOM  
[Parts for ROM_carried from DigiKey](https://www.digikey.com/short/zn95jj)

### ROM_no_carrier
Same as above but on a big pcb with no carrier, instead of a small pcb in a 3d-printed carrier.  

Requires a thinner PCB than normal.  
This PCB may be up to 1.2mm thick.  

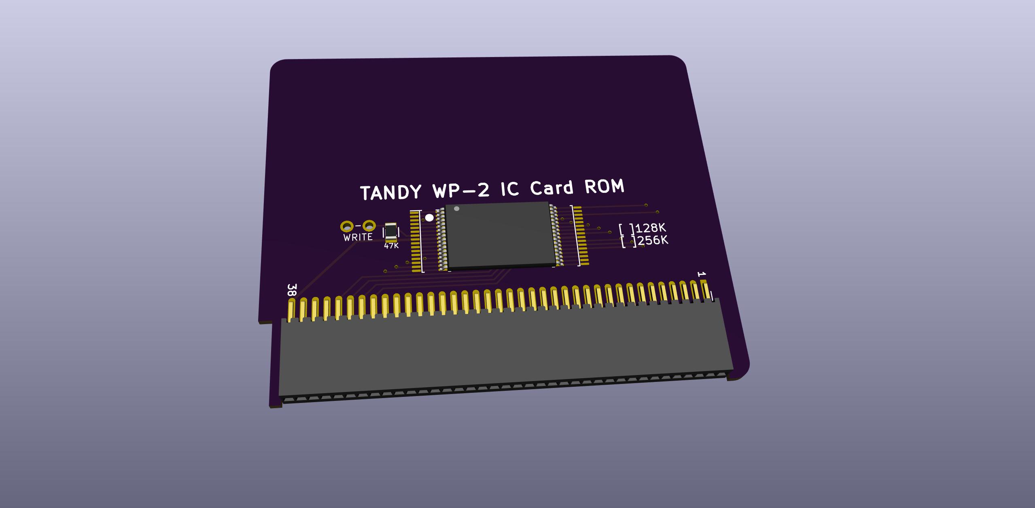
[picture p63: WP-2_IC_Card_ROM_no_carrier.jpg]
  
  

PCB  
[PCB ROM_no_carrier at OSHPark](https://oshpark.com/shared_projects/GTC2pMRm) (Select 0.8mm pcb thickness at checkout)  
[PCB ROM_no_carrier at PCBWAY](https://www.pcbway.com/project/shareproject/WP_2_IC_Card_ROM_no_carrier.html) (Select 1.2mm pcb thickness at checkout)  

BOM  
[Parts for ROM_no_carrier at DigiKey](https://www.digikey.com/short/zn95jj)

## ROM Programming Adapter
Use with a standard eprom programmer such as TL-866, to write either of the ROM cards.

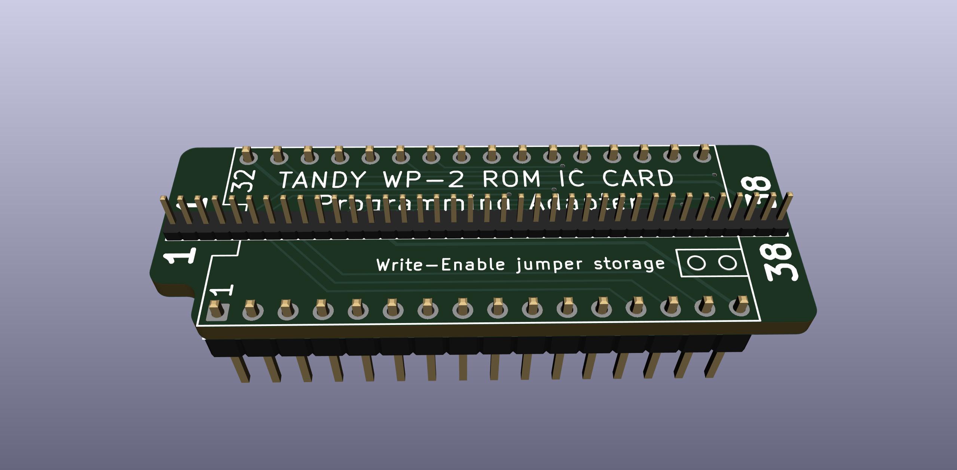
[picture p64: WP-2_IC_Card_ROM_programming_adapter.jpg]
  
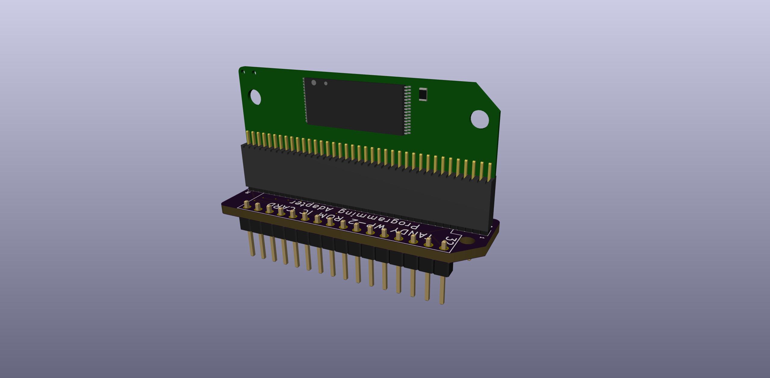
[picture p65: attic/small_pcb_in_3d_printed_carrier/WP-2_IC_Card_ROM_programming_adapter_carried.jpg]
  
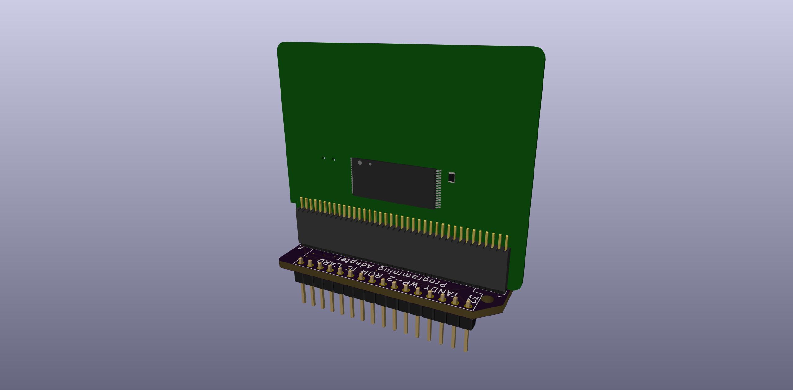
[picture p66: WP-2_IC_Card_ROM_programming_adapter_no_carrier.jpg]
  
  

PCB    
[PCB ROM_programming_adapter at OSHPark](https://oshpark.com/shared_projects/AU1iXOKs)  
[PCB ROM_programming_adapter at PCBWAY](https://www.pcbway.com/project/shareproject/WP_2_IC_Card_ROM_programming_adapter.html)

BOM  
[Parts for ROM_programming_adapter from DigiKey](https://www.digikey.com/short/zn9rqn)

Make a write-enable jumper for the WRITE pads on the ROM IC Cards by taking 2 of the left over 2.54mm pins and solder-bridging the two pins on one side. Pinch the pins together a little to make the fit stiff when plugged into the WRITE holes on the card.

The center line of 1.27mm pins isn't quite tall enough to make good contact with the socket on the ROM card.  
Make the center pins taller this way:  
Start with the pcb you want to solder, and the pin header, and insert the pins into the top of the pcb, as expected, don't solder yet.  
Take one of the extra pcbs (you get 3 to 5 copies of the pcb depending on who you ordered the pcb from) and slide it onto the pins, all the way down to the insulator.  
Now you have a sandwich with two pcbs, and the pin header insulator in between.  
Flip the stack over so that you are looking at the bottom of the main pcb, and the bottom legs of the pins are facing up as though you were about to solder them.  
Take a small hard flat tool like the joined end of a set of tweezers or a spudger stick tool or something, lay the end of the tool flat/sideways on the ends of a few pins, and drive a few of the pins straight in, right down flush with the surface of the pcb. Support the stack by just holding on to the extra pcb, now positioned on the bottom of the stack while it's flipped upside down, and push directly on the end of the pins. The extra pcb holds the pin header insulator in place and lets you drive the pin through the insulator, until the tool hits the surface of the main pcb (the one you will be soldering). Do this for all the pins untill all the pins are pushed through and the tips of the pins are flush with the surface of the main pcb.  
Now apply flux to the pins and solder them. Just put solder on the iron and touch it to the pads, and let the flux bring the solder down into the via, leaving a little round dome.  
After all pins are soldered, slide the extra pcb off the pins. pull from both ends of the pcb at the same time to avoid tilting and binding and bending the pins on the way off. It really wants to do that.  

The point of all that was that now the center line of pins is taller than they would have been and it's now tall enough to make good contact with the socket on the card.  

# Reference Material
[WP-2 Owner & Service Manuals](https://archive.org/search.php?query=Tandy%20WP-2)  
Card slot signals & usage: Service Manual 8-2, C-3. (other places like 4-20, 4-25 not as accurate)  
Executable/"RUN" files: Service Manual 4-16, D-1.  

Pin Socket Header:  
[Original Connectors](ref/JC20-B38S-F1.pdf)  
Datasheet for both the slot in the computer and the connector in the card.  

You can't get the real connector any more, but you can get a generic socket header which fits the pins.  
The pins inside the card slot are 1 row x 38 pins, 1.27mm pitch, 6.0mm long

SAMTEC 8.5mm Pin Socket  
<https://duckduckgo.com/?q=SMS-138-01>  
<https://www.digikey.com/en/products/detail/samtec-inc/SMS-138-01-G-S/9773732>  
<https://www.mouser.com/ProductDetail/Samtec/SMS-138-01-G-S>  

There are less expensive generic female 1.27mm pitch pin headers on ebay and aliexpress etc, but they don't work for this. Sorry :/

RAM:  
Compatible Specs: SRAM, 128Kx8, 5v, Parallel, TSOP-32 (8x20mm) or sTSOP-32 (8x14mm)  
Several parts are compatible. Several examples are listed in the schematic, and the BOM links include a compatibe part.  Here are some pre-loaded searches:  
[DigiKey](https://www.digikey.com/short/zw38nv)  
[Mouser](https://mou.sr/2GcUWHl) (many of the pictures are wrong, so ignore the pictures)  

ROM:  
Compatible Specs: FLASH, 256Kx8, 5v, Parallel, TSOP-32 (8x20mm) or sTSOP-32 (8x14mm)  
As with the SRAM, several parts are compatible. A few example part numbers are listed in the schematic, and the BOM links include a compatible part.  

Notes about the card slot pinout & signals:  
Some places in the Owner's Manual and Service Manual do not describe the IC Card pins accurately. The schematic on page 8-2 in the Service Manual is correct about all the following points.

Pin 2, /DET Card Detect: WP-2 uses to detect the type of card. The pin has a pullup to VDD inside the WP-2. RAM card should connect this pin to GND. ROM card should leave this pin not connected.

Pin 3, CE2, active-high chip-enable: Some places in the Service Manual claim this is an alternative chip-enable, equivalent to and inverse of /CE1. This is not true, and some other places in the service manual are correct. CE2 is not actually the inverse of /CE1 and does not actually change state. This pin is physically hardwired directly to VDD inside the WP-2. It's even a heavy trace that could be used as an alternative power source not just a signal. Since it's not actually switched, it's not the best way to enable/disable the IC. It would work, just that the IC would be enabled 100% of the time that the card was inserted and the WP-2 was powered on. These PCBs don't connect CE2.

Pins 15, 16, 36: Some places in the service manual say these pins are all NC, but they all actually connect to RA5 and IC5.  

Pin 15 -> RA5 -> IC5 pin 66, "S1" on IC5 on the schematic.  
Pin 16 -> RA5 -> IC5 pin 67, "S2" on IC5 on the schematic.  
Pin 15 -> RA5 -> IC5 pin 68, "S3" on IC5 on the schematic.  

RA5 is 5 x 100k pullup resistors to VDD.  
IC5 is a gate array with unknown programming.  

It's possible that the programming inside the gate array does not connect these pins to anything. But since the pins are physically connected to both the pullup resistors and the IC, it means the pins are not actually available for another use the way they would be if they were actually NC.  

For example, to enable writing the ROM card with the programming adapter, yet disable writing any other time, the card needs a pullup on /WE to the IC, and disconnected R/W pin from the card slot. If pins 15 and 16 were really not connected to anything inside the WP-2, then it would be possible to have the programming adapter automatically enable writing by having the R/W-/WE line pass out pin 15 and back in pin 16, and have the programming adapter connect pins 15 and 16 to each other. But since the pins actually do connect to things, don't do that.

Pin 17, A17: Only used for ROM. RAM may only go up to 128K. ROM may go to 256K. The RAM PCBs do not connect A17. The ROM PCBs do.

Pin 37, BCHK/Vchk, Battery Voltage Check: Unknown usage. The schematic on service manual page 8-2 doesn't show Vchk connecting to anything else. I probed all over the board and could not find continuity anywhere, but I couldn't see both sides of the pcb and so could not say for sure that the pin isn't connected to anything. These PCBs don't connect Vchk.  

# TODO
CamelFORTH on ROM?  
But how to construct rom image? Same as RAM (which requires formatting and is a filesystem with multiple files and names and metadata like a disk)? Or raw executable written starting a 0x0000?

Document how to export gerbers for JLCPCB  

Document how to select the right options in JLCPCB  

Format the battery-backed SRAM version, save a few files on it, then use a temporary manually wired programming adapter (NOT the programming adapter for the ROM board), and use a programmer to dump the contents of the SRAM to examine how the WP-2 uses the RAM.  

Add a 5v power output to power a [MounT](https://github.com/bkw777/MounT) ?

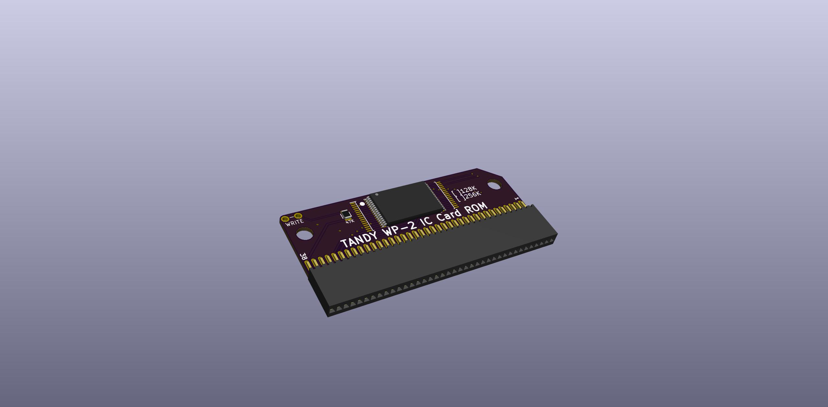
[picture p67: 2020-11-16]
attic/small_pcb_in_3d_printed_carrier/WP-2_IC_Card_ROM_carried_3.jpg

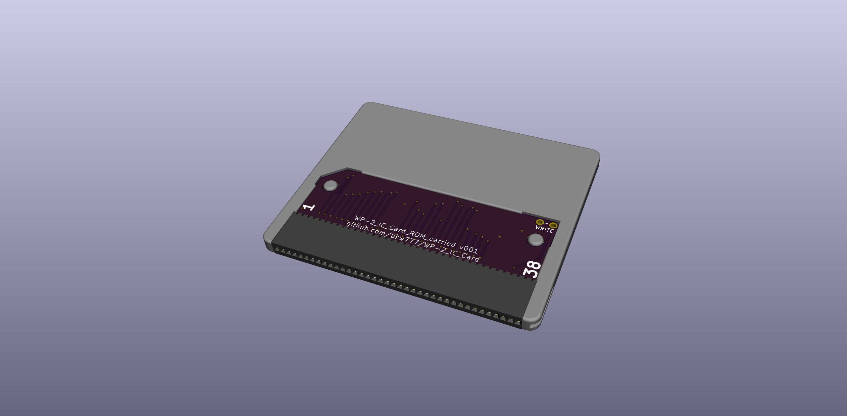
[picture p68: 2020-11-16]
attic/small_pcb_in_3d_printed_carrier/WP-2_IC_Card_ROM_carried_4.jpg

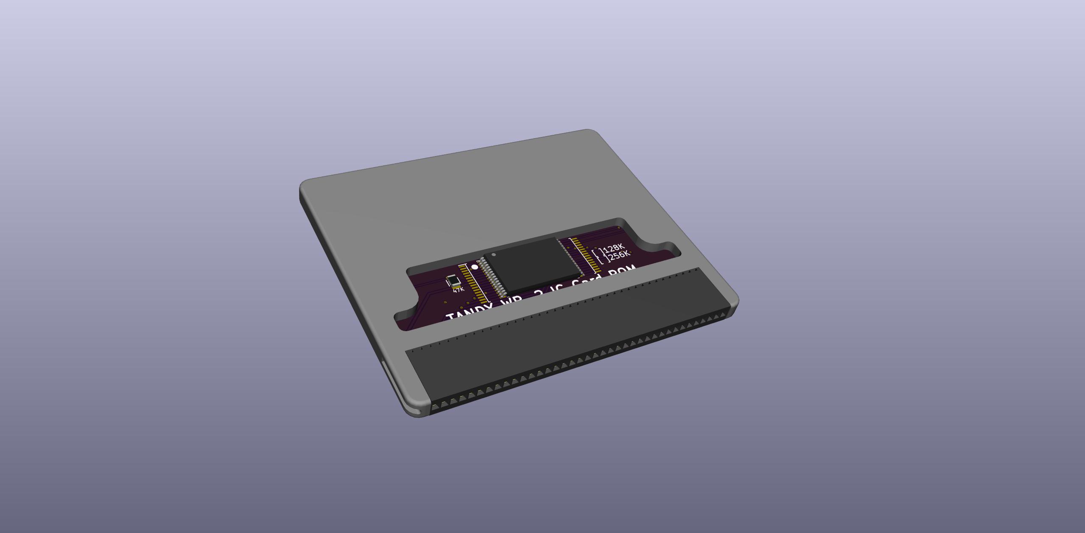
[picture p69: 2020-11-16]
attic/small_pcb_in_3d_printed_carrier/WP-2_IC_Card_ROM_carried_2.jpg

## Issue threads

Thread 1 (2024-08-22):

How should PCBWay handle vias in pads?

jwiede, 2024-08-22:
Brian,

Sent the design to PCBWay only to have them call-out the vias hiding in the pads, and ask whether those should be tented, filled, or what?  WHat is your expected handling for the vias-in-pads on the 015 design of the MRAM 512K?

As you mention having PCBway do them, and even have the designs over on PCBway (where I originally got it from, not stated there either that I or they could find), having explicit details on what options to use, etc. when ordering and how to handle things that will get asked (such as the vias-in-pads question) would definitely help the process.

Thanks!

bkw777, 2024-08-22:
You don't do anything about them. No changes to the soldermask. If a via is in a pad, it just gets soldered along with the pad. They never asked me about that before and I've had a ton of these made while going through different versions. Though never assembly, just the pcbs.

If you're trying to get them populated not just the pcbs, then wait a day and I'll add a branch that has all the vias moved out of pads and add fiducials. For machine/paste soldering, the paste only provides a fixed amount of solder, and vias in pads robs some, leaving the joint light. It's no problem for hand soldering though.

bkw777, 2024-08-23:
I've updated both the SRAM 128K and the MRAM 512K boards to move all the vias out of the pads, added fiducials, added manufacturer part numbers to the schematic, exported bom and centroid files.

The latest release gerbers include all the updates and exported files, and the pcbway page is updated.

jwiede, 2024-08-23:
Brian, thanks so much, I really appreciate all the additional info.

-John W.

________________________________
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

Closed 2024-08-23.

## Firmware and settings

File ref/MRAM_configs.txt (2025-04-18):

WP-2 MRAM card configurations

                         |       U1       |  SW1,D1,  |  JP1    |  JP2  |  JP3
                         |      MRAM      |  R3,R4    |  #DET   |  A17  |  #WE
----------------------------------------------------------------------------------
* 128K RAM               |  MR0A08BCYS35  |  dnp      |  close  |  any  |  close
  128K ROM               |  MR0A08BCYS35  |  dnp      |  open   |  any  |  open
* 512K RAM 4x128K banks  |  MR2A08ACYS35  |  install  |  close  |  1-2  |  close
  512K RAM 2x256K banks  |  MR2A08ACYS35  |  install  |  close  |  2-3  |  close
  512K ROM 4x128K banks  |  MR2A08ACYS35  |  install  |  open   |  1-2  |  open
  512K ROM 2x256K banks  |  MR2A08ACYS35  |  install  |  open   |  2-3  |  open


* normal

The solder jumpers allow to emulate a rom card.

When JP2=2-3:
bank switch 1 or 2 -> bank 1. 3 or 4 -> bank 2

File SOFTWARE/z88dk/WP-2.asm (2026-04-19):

; Template asm for WP-2 executable
; z88dk-z80asm compiler, geany code editor

; geany setup:
; - Install /usr/share/geany/filedefs/filetypes.Z80asm.conf
; - Document -> Set Filetype -> Programming Languages -> Z80asm source file

; build RUN file : z88dk-z80asm -b -o=foo.PR foo.asm
; build ROM image: z88dk-z80asm -DROM -b -o=foo.PI foo.asm

; WP-2 System ROM Calls
CMPHLDE			EQU		0x0020	; Compare HL to DE
CHARSENSE		EQU		0x0100	; Check keyboard buffer, nonblocking get status
CHARGET			EQU		0x0103	; Get one character, wait for input
KILLBUF			EQU		0x0106	; Kill key buffer
SETLOC			EQU		0x0109	; Set cursor location
GETLOC			EQU		0x010C	; Get cursor location
SETCURSORONOFF	EQU		0x010F	; Set cursor on/off
SETCURSORTYPE	EQU		0x0112	; Set cursor type
SETCOLOR		EQU		0x0115	; Set character color
CHAROUT			EQU		0x0118	; Output character to console, no esc seq
PUTCHAR			EQU		0x01A3	; Output character to console, support esc seq
STROUT			EQU		0x011B	; Output string to console, no esc seq
CLS				EQU		0x011E	; Clear screen
BEEP			EQU		0x0121	; Beep a buzzer
CHECKCNCL		EQU		0x0124	; Check that CNCL key is pressed NOW
PRNOUT			EQU		0x0130	; Output one byte of data to printer
PRNSTATUS		EQU		0x0133	; Check printer status
READSLOT		EQU		0x0160	; Read data in a slot
CHGSLOT			EQU		0x0166	; Change slots
RSINIT			EQU		0x0140	; Initialize RS232C (Baud rate etc...)
GETDATALEN		EQU		0x0143	; Get the length of effective data in aux-buffer
SENDDATA		EQU		0x0146	; Output one byte of data to RS232C
GETDATA			EQU		0x0149	; Get data from the aux-buffer
RSCLOSE			EQU		0x014C	; Close RS232C
TAPEIN			EQU		0x0150	; Read data from tape
TAPEOUT			EQU		0x0153	; Write data to tape
MOTORON			EQU		0x0156	; Motor on
MOTOROFF		EQU		0x0159	; Motor off
SYNCREAD		EQU		0x0169	; Read Sync
SYNCWRITE		EQU		0x016C	; Write Sync
LINEIN			EQU		0x01A6	; Cooked line input
LINEIN2			EQU		0x01AC	; Cooked line input with default string
UNGETFORLINP	EQU		0x01A9	; Unget Char for LINEIN and LINEIN2
MALLOC			EQU		0x0170	; Memory allocation
MCHGSIZE		EQU		0x0173	; Changes the size of mALLOCed BLOCK
MFREE			EQU		0x0176	; Free mALLOCed BLOCK
MCLOSE			EQU		0x017C	; Close (save) mALLOCed BLOCK
MNAME			EQU		0x017F	; Names the mALLOCed BLOCK - must before MCLOSE
LIST0			EQU		0x0182	; Initialize file listing - must before LIST
LIST			EQU		0x0185	; Get the file list
OPEN			EQU		0x0188	; Opena file
READ			EQU		0x018B	; Read a file
WRITE			EQU		0x018E	; Write a file
CLOSE			EQU		0x0191	; Close a file
DELETE			EQU		0x0194	; Delete a file
RENAME			EQU		0x0197	; Rename a file
FORMAT			EQU		0X019A	; Format a disk-device
DEVROOM			EQU		0x01C1	; Get devices rest size (remaining 128-byte blocks)
SEEK			EQU		0x01BE	; Seek file pointer - only ram disk & ic card ram disk
WAIT			EQU		0x01A0	; Wait for fixed time in 0.1s
RUNIC			EQU		0x01AF	; Run IC card program
RUNFILE			EQU		0x01B2	; Run a program file
POFFCOUNTPOINTER	EQU	0x01B5	; Get power off counter pointer
SETBTYPE		EQU		0x01B8	; Set battery type
GETWORK			EQU		0x01BB	; Get work area

; I/O Ports
pBANKCTL	EQU		0x51

; Memory Addresses
aROMWINDOW	EQU		0x4000
szROMBANK	EQU		0x4000
aRAMWINDOW	EQU		0x8000
szRAMBANK	EQU		0x8000
aWORKAREA	EQU		0xAC00

; RST Hooks
hCMPHLDE	EQU		0x20	; Compare HL to DE
hBREAK		EQU		0x28	; Debug hook table break pointer
hCALLFAR	EQU		0x30	; Call a routine in another slot

; Keyboard keys
kTAB	EQU		0x0B
kBS		EQU		0x08
kENTER	EQU		0x0D
kESC	EQU		0x1B
kRIGHT	EQU		0x1C
kLEFT	EQU		0x1D
kUP		EQU		0x1E
kDOWN	EQU		0x1F
kDEL	EQU		0x7F

; vt52 esc sequences
eUP		EQU		'A'
eDOWN	EQU		'B'
eRIGHT	EQU		'C'
eLEFT	EQU		'D'
eHOME	EQU		'E'
eEOS	EQU		'J'
eEOL	EQU		'K'
eCP		EQU		'Y'	; cursor position, follow with line column, ex: kESC eCP line column
eENQ	EQU		'Z'

; Keyboard modifiers (L bits after CHARSENSE or CHARGET)
mF2			EQU		0	; BIT mF2,L NZ = F2 is pressed
mF1			EQU		1	; BIT mF1,L NZ = F1 is pressed
mCTRL		EQU		2	; BIT mCTRL,L NZ = Ctrl is pressed
mRSHIFT		EQU		3	; BIT mRSHIFT,L NZ = Right Shift is pressed
mLSHIFT		EQU		4	; BIT mLSHIFT,L NZ = Left Shift is pressed
mCAPSLOCK	EQU		5	; BIT mCAPSLOCK,L NZ = Caps Lock is on
mCODE		EQU		6	; BIT mCODE,L Z = ALT=GRPH, NZ = ALT=CODE
mALT		EQU		7	; BIT mALT,L Z = normal, NZ = ALT


;------------------------------------------------------------------------------
; HEADER
;------------------------------------------------------------------------------

; PI and PR headers are not the same length

IFDEF ROM	; Header for WP-2 executable ROM image

ORG aROMWINDOW		; rom bank window
DB "PI"				; ID
DW 0				; reserved
DB 0x0F				; bank number (15-31), 0x0F = first 16k of rom ic card
DW START			; entry addr (service manual p37 incorrect DB, p132 correct DW)
DW 0				; reserved

ELSE		; Header for WP-2 executable RUN file

ORG aWORKAREA-8		; application_work_area - length_of_header
DB "PR"				; ID
DW PRGEND-PRGTOP+1	; length
DW START			; entry addr
DW 0				; located addr (0="here")

ENDIF


;------------------------------------------------------------------------------
; BODY
;------------------------------------------------------------------------------
PRGTOP:
START:

; ...program code...

EXIT:
	; A = exit flag to system
	;LD A,0xFF	; A=0xFF = keep program area as driver/filter/tsr
	XOR A		; A=0x00 = return program area to system
	RET

; ...program code...

PRGEND:
END:

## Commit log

2020-09-29 reduce TSOP to 1.0 mm height so roof can be 0.7mm thick for printing
    [WP-2_IC_Card.stl]
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2020-10-01 test keep-alive cap and 256K on the bare version
    [WP-2_IC_Card_RAM_128K_bare.sch, WP-2_IC_Card_RAM_128K_v2_bare.kicad_pcb]
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2020-10-02 repair mesh glitches, update 3d print links
    [Carrier_v003.step, WP-2_IC_Card_Carrier_v003.stl]
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2020-10-06 better silkscreen on v003, pics, prep v003 w/zone will be next main version
    [WP-2_IC_Card_RAM_128K_v003_zone_fill.kicad_pcb]
2020-10-06 reorganize files & names, v001 chamfer to widen front opening to install/remove pcb.
    [WP-2_IC_Card_Carrier_v001.step, WP-2_IC_Card_Carrier_v001.stl, WP-2_IC_Card_Carrier_v003-g.step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]
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2020-10-30 reorganize filenames, reset all versions to 001 for first official release
    [Solder_Bridge_0.7x2.0_rounded_rect.step, WP-2_IC_Card_Carrier_v001.step, WP-2_IC_Card_Carrier_v001.stl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]
2020-10-31 fix ROM flash chip pinout
    [WP-2_IC_Card_ROM_carried.kicad_pcb, WP-2_IC_Card_ROM_carried.sch, WP-2_IC_Card_ROM_no_carrier.kicad_pcb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]
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2020-11-13 increase via sizes and min soldermask width for PCBWAY
    [WP-2_IC_Card_RAM_cap_batt_no_carrier.kicad_pcb, WP-2_IC_Card_RAM_cap_carried.kicad_pcb, WP-2_IC_Card_ROM_carried.kicad_pcb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]
2020-11-16 move 3d-printed carrier version to the attic :/
    [BK-5067.STEP, C_0805_2012Metric.step, D_SOD-523.step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]
2020-11-16 more clean up from ditching the small boards
    [WP-2_IC_Card_RAM.kicad_pcb, WP-2_IC_Card_RAM.sch, WP-2_IC_Card_ROM.kicad_pcb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]
2020-11-17 missing /CE1 on programming adapter
    [WP-2_IC_Card_ROM_programming_adapter.kicad_pcb]
2020-11-17 broken edge-cut outline on programming adapter
    [WP-2_IC_Card_ROM_programming_adapter.kicad_pcb]
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2021-01-14 v003 - edge cut finger pulls, easier diodes and batt holder for RAM
    [SOT-23.step, WP-2_IC_Card_RAM.BOM.csv, WP-2_IC_Card_RAM.kicad_pcb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]
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2021-03-07 fix render, RAM card needs ENIG for battery
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2021-03-18 fix wiring error on write-enable switch on ram card
    [WP-2_IC_Card_RAM.kicad_pcb, WP-2_IC_Card_RAM.sch, WP-2_IC_Card_RAM_programming_adapter.kicad_pcb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]
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2023-01-01 3d-printable cover, add decoupling, simpler batt change cap, simpler breakout
    [BATT_CR2016.step, PinHeader_2x19_P2.54mm_Vertical.step, WP-2_IC-Card_Breakout.BOM.csv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]
2023-02-02 simpler caps for ram card, 3d-printed cover, new WIP 4-bank MRAM card
    [CUS-14TB.stp, C_0805_1mm.step, C_1206_1mm.step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]
2023-02-14 mram 512 level-shift parts, battery backed ram top cover
    [WP-2_IC-Card_Cover.scad, WP-2_IC-Card_MRAM_512.kicad_pcb, WP-2_IC-Card_MRAM_512.kicad_sch]
2023-02-16 minor code touchups in the scad cover model
    [WP-2_IC-Card_Cover.scad]
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2023-12-22 MRAM level shifters, delete FRAM, local datasheets in local symbols
    [TSSOP-6.step, WP-2_IC-Card_Breakout.kicad_pcb, WP-2_IC-Card_Breakout.kicad_sch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]
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2024-08-22 mram move vias out of pads, add MPN and export fab_bom.csv
    [WP-2_IC-Card_MRAM_512.fab_bom.csv, WP-2_IC-Card_MRAM_512.kicad_pcb, WP-2_IC-Card_MRAM_512.kicad_sch]
2024-08-22 ram 128 move vias off pads and add MPN and fab_bom.csv
    [WP-2_IC-Card_Breakout.kicad_pcb, WP-2_IC-Card_RAM.fab_bom.csv, WP-2_IC-Card_RAM.kicad_pcb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]
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2024-10-03 local symbol & footprint library organization, add shielded mram version
    [WP-2_IC-Card_Breakout.kicad_pcb, WP-2_IC-Card_Breakout.kicad_sch, WP-2_IC-Card_Breakout.stl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]
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2024-10-07 redraw board outline and copy to all boards
    [WP-2_IC-Card_Breakout.kicad_pcb, WP-2_IC-Card_MRAM_512K.kicad_pcb, WP-2_IC-Card_MRAM_512K_shielded.kicad_pcb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]
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2025-04-18 MRAM card that supports both 128K and 512K, and supports emulating rom
    [MRAM_configs.txt, WP-2_IC-Card_Cover.scad, WP-2_IC-Card_MRAM.bom.csv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]
2025-04-18 new mram pcb touchups, routing /WE, solder jumper pads
    [WP-2_IC-Card_MRAM.bom.csv, WP-2_IC-Card_MRAM.kicad_pcb, WP-2_IC-Card_MRAM.kicad_sch]
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2025-04-19 update covers for flash & mram with bank sw & write sw
    [WP-2_IC-Card_Cover.scad, WP-2_IC-Card_MRAM.kicad_pcb, WP-2_IC-Card_MRAM.kicad_sch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]
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2025-04-22 SRAM compatible with 512K, pullup /WE, TSOP32 footprint, cfg jumpers
    [WP-2_IC-Card_MRAM.kicad_pcb, WP-2_IC-Card_MRAM.kicad_sch, WP-2_IC-Card_ROM.kicad_pcb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]
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2025-04-23 sram move switch & batt a little for better cover shape
    [WP-2_IC-Card_Cover.scad, WP-2_IC-Card_SRAM.kicad_pcb, sram.pcb.stl]
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2025-04-26 refactor cover scad more, cover models makefile, adjust new sram switch & batt positions
    [MRAM.pcb.stl, ROM.pcb.stl, SRAM.pcb.stl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]
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2025-04-27 sram battery holder backwards, update cover, solder jumper footprints
    [SRAM.pcb.stl, WP-2_IC-Card_Cover.scad, WP-2_IC-Card_SRAM.kicad_pcb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]
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2025-05-07 ROM fix 128K compat, add 64K compat
    [WP-2_IC-Card_ROM.kicad_pcb, WP-2_IC-Card_ROM.kicad_sch]
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2025-05-09 add fancy programming adapters, horizontal tray, & full socket
    [WP-2_IC-Card_programming_adapter.kicad_pcb, WP-2_IC-Card_programming_adapter.kicad_sch, WP-2_IC-Card_programming_adapter_full_socket.kicad_pcb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]
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2025-06-18 don't connect the slider with sprues by default
    [WP-2_IC-Card_Cover.scad]
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2025-09-26 ROM card must not scramble the data or address lines
    [WP-2_IC-Card_ROM.kicad_pcb, WP-2_IC-Card_ROM.kicad_sch]
2025-09-27 rom card adhere to pcbway soldermask web limit 0.22mm
    [WP-2_IC-Card_ROM.kicad_pcb]
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2025-10-07 adhesive tape, pics, tiny routing nudges, tsop2-44 model, grid alignment
    [WP-2_IC-Card_MRAM.kicad_pcb, WP-2_IC-Card_MRAM.kicad_sch, WP-2_IC-Card_ROM.kicad_pcb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]
2025-10-07 ROM A4 A5 A10 A11 swapped
    [WP-2_IC-Card_ROM.bom.csv, WP-2_IC-Card_ROM.kicad_pcb, WP-2_IC-Card_ROM.kicad_sch]
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2025-10-11 rom write sw add s3, rom default 256k
    [ROM.pcb.stl, WP-2_IC-Card_Cover.scad, WP-2_IC-Card_ROM.bom.csv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]
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2025-10-22 silkscreen, remove old 128k sram, new programming adapter
    [WP-2_IC-Card_Cover.scad, WP-2_IC-Card_Programming-Adapter_Horizontal_Floor.kicad_pcb, WP-2_IC-Card_Programming-Adapter_Horizontal_Main.kicad_pcb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]
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2025-11-03 silkscreens, board outlines, switch slider, covers fitment, copper to edge
    [MRAM.pcb.stl, ROM.pcb.stl, SRAM.pcb.stl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]
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2026-04-09 MemUtil - fix manual flash write banksw bug, remove MX & MXs, add abort counter to avoid hang, add z88dk
    [MemUtil.asm, WP-2.asm]
2026-04-09 update template asm for correct .PI rom image output
    [WP-2.asm]
2026-04-16 add wp2 & z80 docs, MemUtil - refactor hex input/output, correct exit
    [MemUtil.asm, WP-2.asm]

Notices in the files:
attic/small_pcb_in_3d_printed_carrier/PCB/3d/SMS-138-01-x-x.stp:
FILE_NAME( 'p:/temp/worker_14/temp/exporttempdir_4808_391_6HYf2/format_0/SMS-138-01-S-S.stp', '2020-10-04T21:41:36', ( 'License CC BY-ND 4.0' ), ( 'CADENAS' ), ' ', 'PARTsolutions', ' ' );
